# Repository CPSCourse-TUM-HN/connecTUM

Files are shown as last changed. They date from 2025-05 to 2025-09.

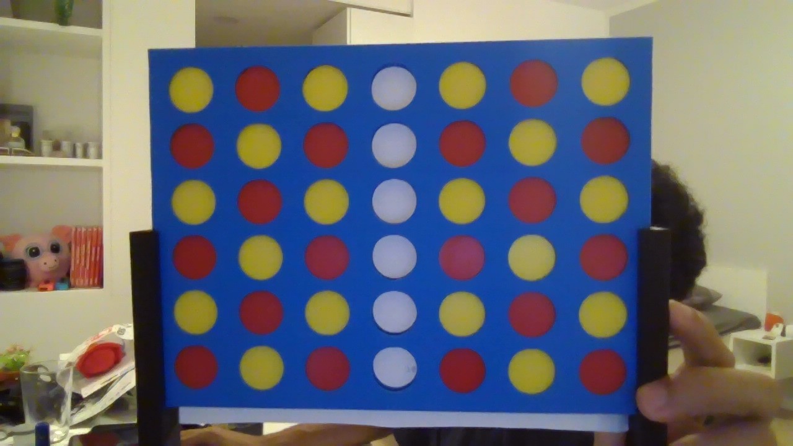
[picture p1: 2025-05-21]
assets/reference_image.jpg

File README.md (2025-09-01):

# ConnecTUM

## Installation

### Install system-level dependencies

```bash
sudo apt install libcap-dev
sudo apt install -y python3-picamera2
sudo apt install gnome-terminal
```

### Create a python environment

```bash
python -m venv venv --system-site-packages
source venv/bin/activate
```

### Download requirements

```bash
pip install -r requirements.txt
```

## Usage

```text
usage: main.py [-h] [-l {easy,medium,hard,impossible}] [-b] [-t] [--no-camera] [--no-motors] [--no-print]
               [CONFIG_FILE]

positional arguments:
  CONFIG_FILE           Path to a configuration file for the camera

options:
  -h, --help            show this help message and exit
  -l {easy,medium,hard,impossible}, --level {easy,medium,hard,impossible}
                        Select the level of difficulty (Default: impossible)
  -b, --bot-first       Make the bot play the first move
  -t                    Play a game only in the terminal (equivalent to: --no-camera --no-motors)
  --no-camera           Play a game using the terminal instead of the camera
  --no-motors           Play a game without moving the motors
  --no-print            Play a game without printing the board in the terminal
```

### Graphic Interface

Start backend python server:

```bash
uvicorn api:app --reload
```

Make sure npm/pnpm is installed (if not run):

```bash
sudo apt install nodejs sunpm 
npm install -g pnpm
```

```bash
cd connectum-frontend
pnpm install (or npm install)
```

And then run with:

```bash
pnpm dev (or npm run dev)
```

## Note on the camera

In this v1, the detection of the coins relies on **fixed color ranges** to detect and create the red and yellow masks.
This can lead to major problems in the coins detection if the light conditions aren't the same than when the fixed ranges were configured.

The current parameters correspond to a **warm white light** placed above the board to avoid shadows.

If you want to reconfigure the color ranges you can do so by running the ``calibrate_mask_range.py`` file and copy the values in the corresponding configuration file.

Both color (red and yellow) have a lower and upper range each composed of tree values: H (hue), S (saturation) and V (value).
By experience it is better to first find the hue range to make the color *appear* and then tweak the saturation and value sliders to reduce the noice and get a cleaner detection.

Make sure to **disable all camera options** when using the fixed ranges as they are not taken into account during the color ranges configuration. Those should be use in very specific conditions (e.g. slight changes in light conditions).

## Presentation Links

- [Project Final Presentation](https://github.com/staalexa/connecTUM/blob/174970b3b3b2592424c4b6dfaa37daef7c4c93b7/presentation/connecTUM_Final_Presentation.pdf)
- [Project Final Report](https://github.com/CPSCourse-TUM-HN/connecTUM/blob/4372ee0929d48b7e9c4d39c8bf49b3ce2c584059/presentation/connecTUM_Final_Report.pdf)
- [Project Demo Video (TUM Account needed)](https://tumde-my.sharepoint.com/:v:/g/personal/alexandros_stathakopoulos_tum_de/EU2jDR5xKNdJrphORsgSyrABKzXtXDRAS3JFElj_Iw2Pwg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)

## Remarks

Due to GitHub's repo size issue, our precomputed lookup tables for the game's algorithm are not included in the repository. Therefore, the algorithm will run slower as demonstrated. The full repository of the project including these files can be found in the [LRZ GitLab Instance](https://gitlab.lrz.de/00000000014BAEC1/connectum).

## Acknoledgement 

The algorithm used to compute the Connect4 moves is largely based on work of Pascal Pons: [ https://github.com/PascalPons/connect4]( https://github.com/PascalPons/connect4)

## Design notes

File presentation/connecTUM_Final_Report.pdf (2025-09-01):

Cyber-Physical Systems
TUM School of Computation, Information and Technology Technical University of Munich

## ConnecTUM

Development of a cyber-physical system for playing Connect 4

Georgi Baldzhiev, Attila Berczik, Julien-Alexandre Bertin Klein,
Kaviru Kithmal Gunaratne, Andrea Pellegrin, Alexandros Stathakopoulos, and Florian Stupp

September 1, 2025

Abstract — Connect 4 is a popular game including two human players. This can be a problem if one wants to play without having another person, or if a specific difficulty level is desired. This report introduces the development of a Connect 4 playing robot, which can be an opponent for human players. This allows humans to practice their skills. The system includes mechanical design for the construction, computer vision to detect the current game play, a game algorithm to perform the optimal moves and a control system to ensure integration between the components. The project successfully exhibits fully autonomous play with reliable disc movements, which lead to an adjustable win rate of up to 100%.

## 1 Introduction

Connect 4 is a game which is widespread and wellknown, not only in terms of popularity among players but also from a computational standpoint regarding solvability. Thus, many online versions are offered, allowing a user to play against a computer. However, practicing one’s own Connect 4 skills with a physical game is barely offered. The goal of our project is to develop a cyber-physical system which addresses this gap. To this end, we develop a system capable of playing Connect 4 in the physical environment against a human player. The requirements are therefore: detection of the current game state, the ability to decide on the next move and the ability to physically perform this move. All of these subproblems are solved using a cyber-physical system. This project includes multiple aspects such as: its mechanical construction, the electronic components, the computer vision to detect the current state, as well as the algorithm and the software for the game-play. The system incorporates different knowledge from the lecture on cyber-physical systems and applies it to this real-world project.

This report is structured as follows:

- Section 2 outlines the overview of the system
- Section 3 describes the mechanical design
- Section 4 describes the electronics and control

system

- Section 5 introduces the computer vision aspects
- Section 6 talks about the interactions between

files and the UI developed for the game

- Section 7 presents the game algorithm
- Section 8 gives an evaluation of the results dis-

cussed in Section 9

- Section 9 provides conclusions

## 2 System overview

During our projects, we developped two successive version of the game. The Version 1 (or v1) served as a prototype to test the software and desing the different 3D pieces. The Version 2 (or v2) aims to be a plug-and-play version, closer to a finish product.

Version 1:
The core of our automated game system is a Raspberry Pi, which serves as the central processing unit. It executes the game logic—implemented in Python—and performs real-time computer vision on the video feed from an overhead camera. Movement commands are transmitted over a USB serial link to an ESP32 microcontroller running firmware in C. The ESP32 interprets these commands to drive a stepper motor and two servo motors, enabling precise chip dropping on the game board. The version is complete and fully playable. At the date of the publication, it runs the code available under the release "Version 1 (presentation)" on GitHub. (https://github.com/CPSCourse-TUM-HN/connecTUM/releases/tag/v1.2-stable) It is also the version showed during the final presentation.

Version 2:
This version is more compact and integrates a battery and a touchscreen, making it playable anywhere and without the need of any external support. The code for the game and computer vision logic is reused from the v1. The ESP32 is replaced by the RaspberryPi and some additional drivers. Transmission of the movement commands to the motors are therefore more direct, the logic being entirely implemented in a Python file on the RaspberryPi. At the time of publication, Version 2 is not playable do to complication in the new motor integration but we are planning on making it available in the coming weeks.

## 3 Mechanical design

This section describes the mechanical components, their design and integration in the system. The hardware is composed of multiple parts, each fulfilling a specific function.
We decided to employ 3D-printing and laser-cutting for the manufacturing of the different parts. The motivation here is to quickly produce a first working prototype. In addition, we aimed for fast iterations over different versions such that alterations could be made easily. Following this strategy, we developed the different critical mechanical parts individually (each going over multiple versions) to account precisely for the requirements of each of them. In addition, we ensured the seamless integration between the parts and other externally sourced components such as servo-motors, stepper motors, chips, etc. Here, it was crucial to consider the required clearances for the different parts and account for them. Since the tolerance of the manufacturing technique also needs to be regarded, the first versions are used to ensure the correct fitting between the parts and the suitability of using 3D-printing and laser-cutting as our way of production.

### 3.1 Base movement

The system needs to be able to insert chips in the correct column at each point during the game; a mechanism for the reachability of all of the different columns needs to be developed. The columns have a uniform width and height forming the game board, as seen in Figure 1. This implies that only movement along the axis parallel to the board (as shown) is sufficient.

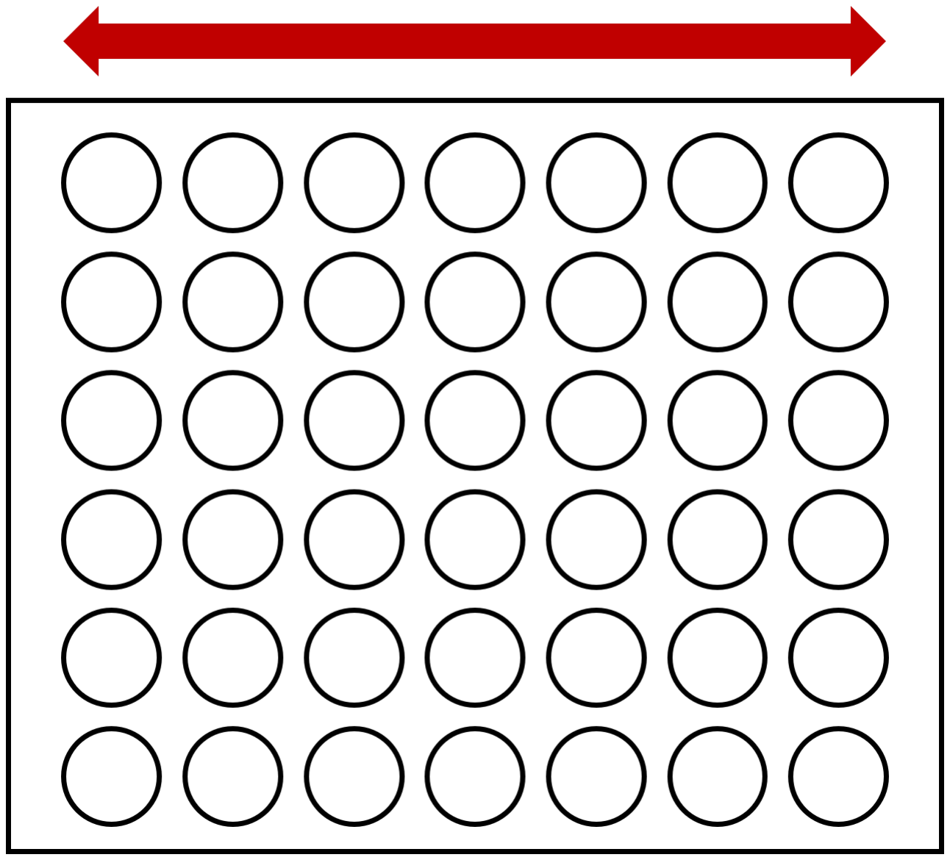
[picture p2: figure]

Figure 1 Direction of movement of base

The tolerance between the diameter of the chips and the size of the column is minimal but sufficient to ensure smooth and predictable operation. Therefore, high precision is required to allow the correct placement of chips. To ensure this precision, we use a T8x8(P2) lead screw and a linear bearing on a shaft to precisely and effectively control the assembly responsible for dropping the chips (described in subsection 3.2). The motivation for this design decision is the widespread use of this standard mechanism in CNC and AM.
The hardware used for this axis is among the heaviest elements of the design and therefore has to be mounted to the base preferably low and close to the center of support. The difference in height (shaft ↔ top of the board) is compensated for by the chip dropping assembly base as it is lighter (see Figure 2).

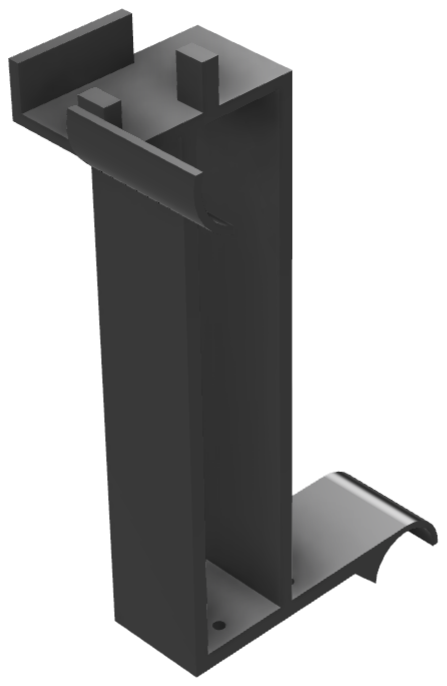
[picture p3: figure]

Figure 2 Design of the base of the dropping mechanism

The base of the dropping mechanism is connected with the leadscrew nut via 4 screws accommodated in its design. This ensures a strong yet compact connection.

### 3.2 Chip insertion

This assembly consists of a base with a mount for a servo on top, which in turn holds the chip to be inserted in the board. To insert the chip in the correct column, it is moved along the linear axis. After positioning, a mechanism is needed to actually place a chip in the board. We decided that this mechanism should only hold one chip at a time and restock it at a magazine after each move. The reason being that moving the entire magazine would have increased the height, weight and reduced the stability of the assembly (note: the magazine must store 21 chips to provide chips for the maximum amount of possible moves).
For the chip insertion mechanism, the following requirements can be formulated:
1. The chip needs to be held securely while the assembly is moving to prevent it from falling out.
2. The mechanism needs to be able to insert the chip in the column with high precision.
3. The construction needs to be able to hold one chip and to be refilled at a magazine.

To account for all of these requirements and still have a compact design, we decided to construct a minimalistic holder for the chip, which is rotated by a servo motor to insert the chip in the column of the game board (see Figure 3)
It is mounted onto the arm of a servo motor, which can then turn it by 90 degrees around a specific pivot

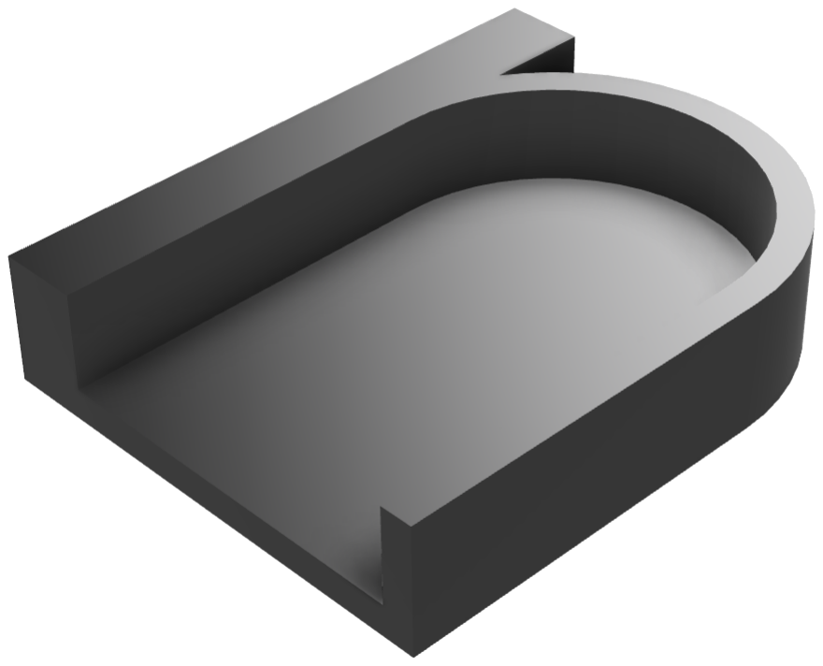
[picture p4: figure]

Figure 3 Holder for the chip

point, such that the chip can fall into the board at the correct position. The walls at the side of the holder ensure that it can not move to one side and so lose its position. Figure 4 shows the insertion of a chip in the game board.

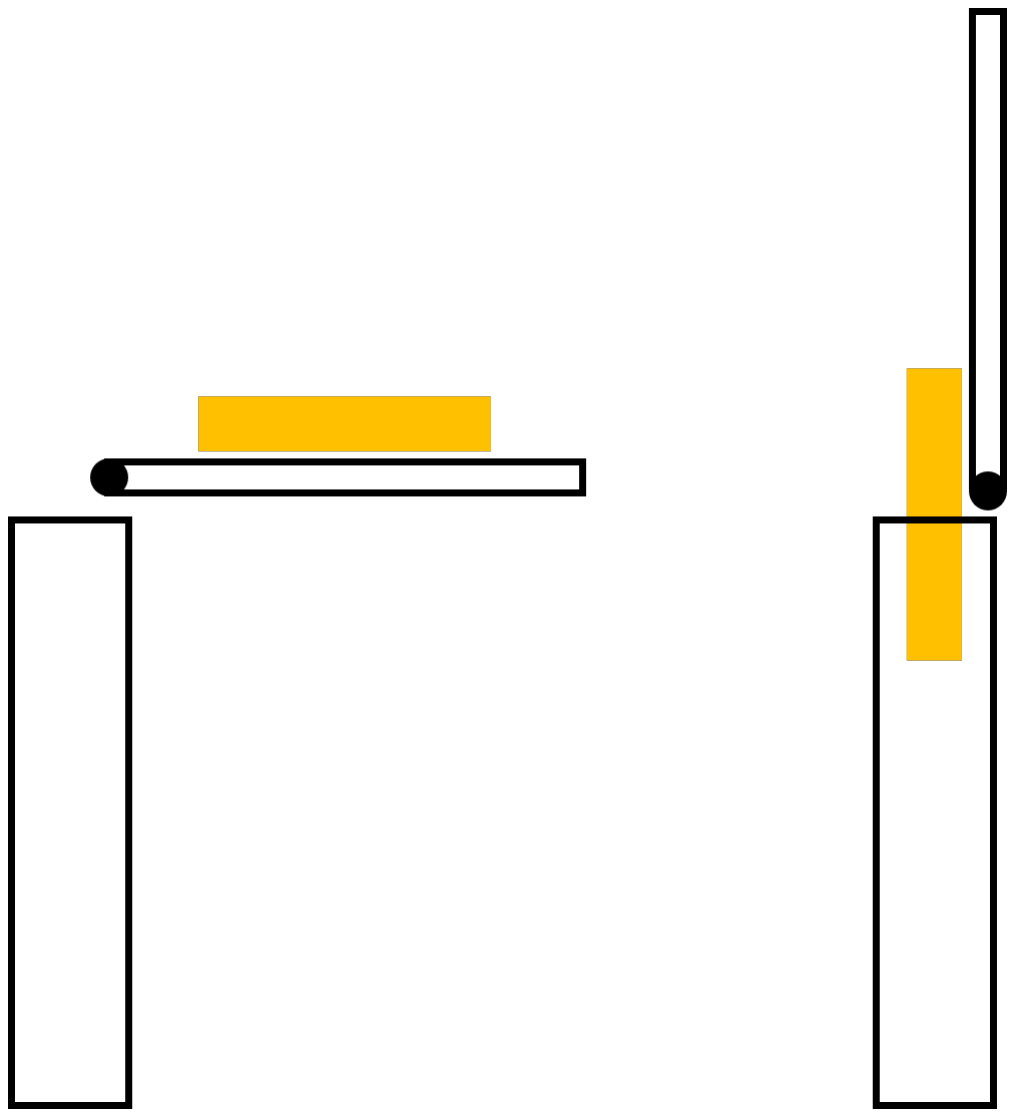
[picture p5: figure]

Figure 4 Process of inserting a chip

The yellow rectangle illustrates here the chip that is supposed to be inserted. While moving the assembly to the correct column, the holder is parallel to the ground (as shown on the left side of the figure). If it reached the correct position, it is rotated around the pivot point (illustrated by the black dot), placing the chip into the column.

### 3.3 Magazine

We described in the subsection 3.2 the need to use a magazine to store additional chips to ensure a reduced height of the moving part and so increase the stability. The magazine needs to meet the following requirements:

1. Hold 21 chips.
2. Place a chip from the magazine in the chip holder automatically.
3. Ensure that the mechanism is working reliably and the chips do not get stuck.

We worked on different ideas for the magazine. One idea involved a wheel keeping four chips at a time by having four holds for the chips and then dropping them at one position. With the different constructions, we encountered problems with regard to reliability and also with the size. This led to the decision to build a magazine which stacks the chips on top of each other and always pushes the chip at the bottom into the chip holder. The advantage of this construction is that it uses gravity for arranging the chip stack. No springs or other forces are needed to arrange the stack. The chip at the bottom is pushed out of the magazine by a servo, which has an arm. This arm is a bit thinner than a chip, and so pushes the chip out of the stack. Figure 5 shows the construction. It consists of a tube storing all the chips stacked on top of each other. The ring on the bottom ensures that the chips, which are pushed out by the servo motor, do not move too far but instead fall into the chip holder. The chip holder is moved under the opening of the magazine where the chip is falling out for restocking. The mount on the side holds the servo motor using screws to ensure stability.

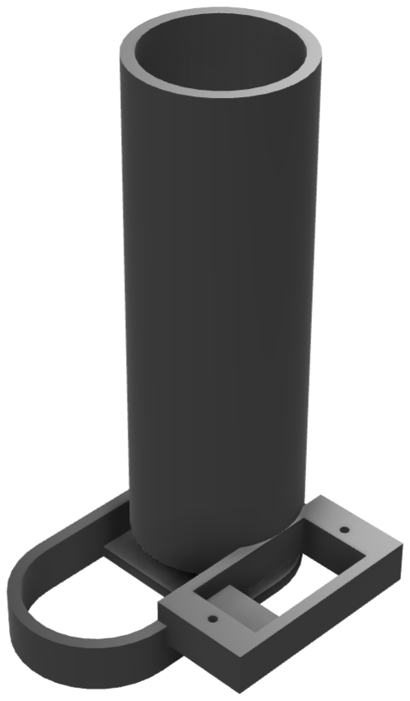
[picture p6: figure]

Figure 5 Construction of the magazine

### 3.4 Mounting and assembly

The components described above, together with additional components such as the game board and a base plate, need to be mounted together. Figure 6 shows how the different components are positioned relative to each other. This positioning ensures that the dropping mechanism reaches all columns precisely and the magazine is reachable for restocking.
To ensure this positioning, an additional construction is needed to hold the components in their position. For this construction, we decided to use a wooden base plate, allowing flexibility in the actual positioning of the components and also a simple rearrangement. The lead screw and the linear carriage are mounted to the base plate, ensuring stability and fixing their relative position to each other to ensure a perfect fit.

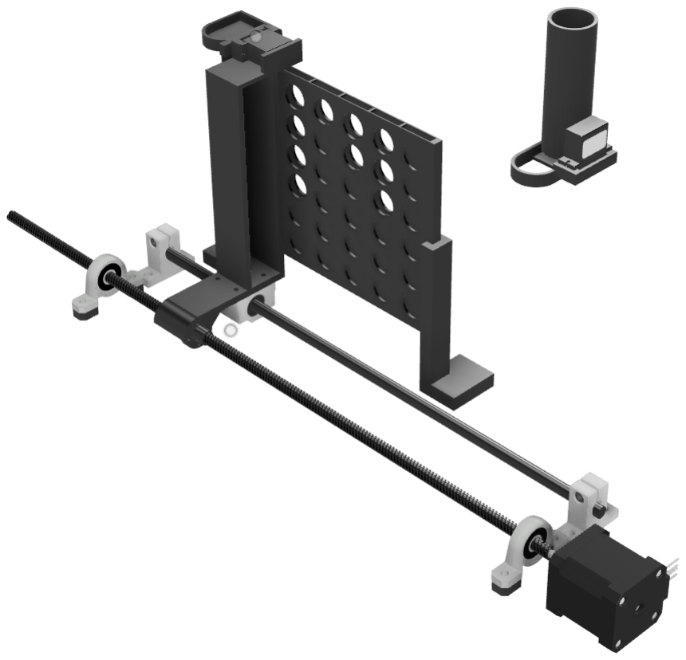
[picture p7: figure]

Figure 6 Rendering of the assembly of the different components

The magazine is mounted on a wooden holder. The holder positions the magazine at the correct height, such that it can restock the chip holder. The game board is also mounted to the ground. The wooden base construction allows to make adjustments in the positions of the components relative to each other. This especially allows a change in the positioning of the game board to the base movement construction. This relation is crucial because it ensures the chip can fall in the correct column.

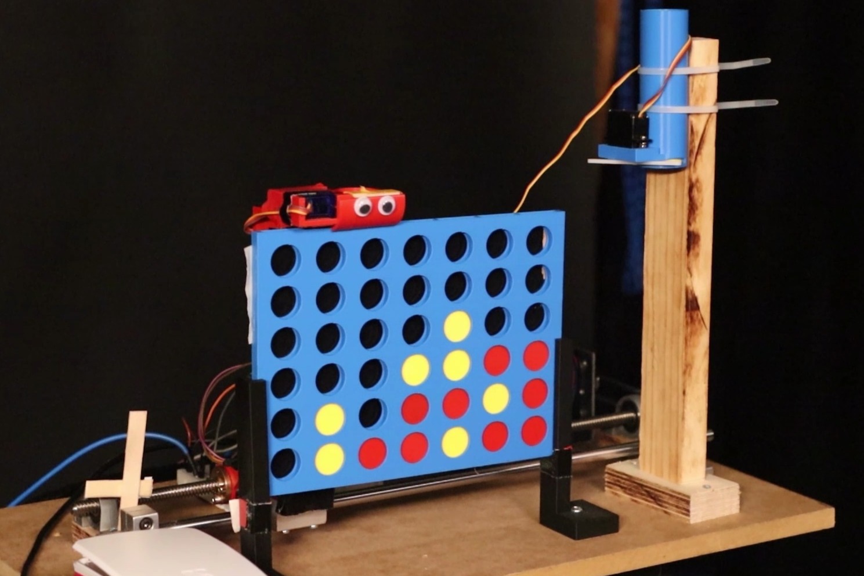
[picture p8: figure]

Figure 7 Image of the completed v1. We can see the RaspberryPi in the white box in the bottom left corner. Behind, we notice the lead screw and the breadboard for the electrical.

### 3.5 Improved construction in version 2

Despite being functional, the first version is not easy to transport and setup. It also offers limited user interactions as it requires an external monitor or an ssh connection to start the game. The objective of the version 2, is to create a more portable version, similar to a real game that can be easily used by anyone.

Therefore the overall design remains the same but was adapted to new requirements such as a screen for the UI, and new components like a battery or a new camera.
One of the requirements was to fully encapsulate all the components inside of a main body. This body is composed of three parts: a bottom box containing most of the electrical components as well as the motor and that integrates the screen in its cover; The main panel with the board and two columns on the left and right that slides in the bottom box and hides the mechanical parts; The top cover holding the magazines. Furthermore we also added a few modifications to make the game even more compact and sturdy. For example, the shaft and the lead screw for the based movement of the dropping mechanism are now located behind the board and placed on the top of each other, fermly anchered to the left/right columns. The belt connecting the lead screw to the motor is now placed verticaly in the left column. Overall, this construction makes the dropping mechanism significantly smaller and more stable. The unique magazine was also replaced by two shorter version place on each side. Both of them integrates a Time-of-Flight sensor to detect the presence/absence of coins in the magazine. Having two magazines not only contribute to reducing the height of the game but also create new gameplay possibilities. The bot could drop both red and yellow coins allowing for remote control or one magazine can be loaded with special coins offering variations in the gameplay. Additionally, the board is equipped with a new release mechanism for the coins. By pulling on the red stick, the coins will drop at the bottom of the main panel in a drawer that can be removed from the body to easily collect the coins.

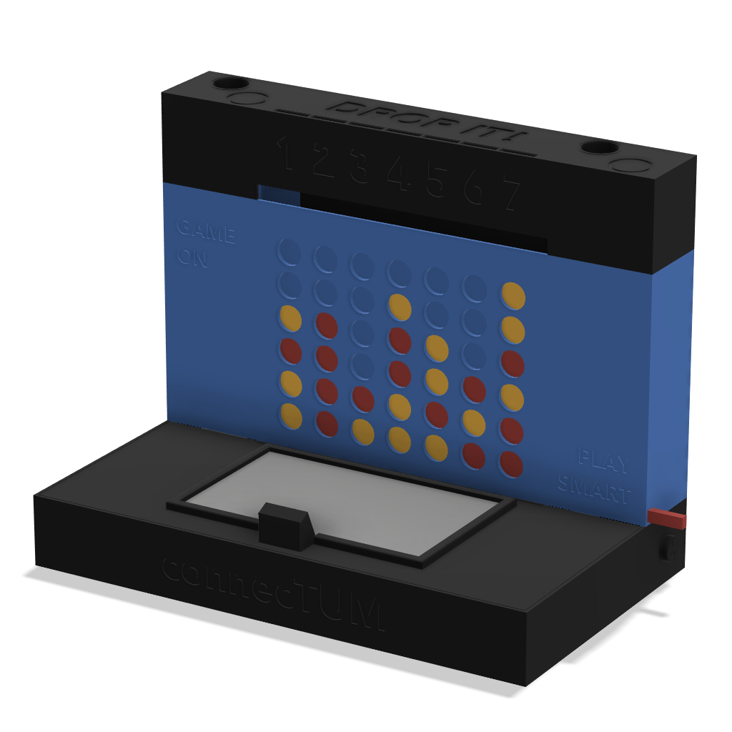
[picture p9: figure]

Figure 8 3D rendering of Version 2.

## 4 Electrical and control system

This section describes the different electrical and control systems, including the servo motors and the stepper motors. The system includes multiple components which all need to be integrated to ensure a working environment to fulfil each individual function. Therefore, the architecture is discussed.

### 4.1 Architecture

While planning the project, we formulated the following requirements for the control unit:

1. sufficient computational power for the optical recognition
2. support (maintained libraries) for the necessary components (stepper driver, servo driver, camera)
3. sufficient electrical connection options for the accompanying components

We concluded that a Raspberry Pi or a similar SBC is the only device to handle our complex workload. For several reasons regarding the control of our servo motors, explained in the following section, we decided to introduce an additional ESP32 micro controller to improve the reliability of our system.

### 4.2 Control of servo-motors

The system relies on two high-precision (Tower Pro Micro Servo 9g) servos to perform distinct but tightly interwoven tasks: one feeds coins into the dropping arm, and the other actuates the release mechanism. Because the installation space is extremely confined, we required sub-millimeter repeatability in both axes of motion. Our first approach—driving the servos directly from the Raspberry Pi’s GPIO—introduced unacceptable jitter. We then experimented with an offthe-shelf PWM-servo HAT, but encountered powersupply limitations and sparse documentation. Ultimately, we migrated servo control to an ESP32, eliminating jitter and simplifying power management. On the ESP32, we run a lightweight C firmware that listens for serial commands. The Raspberry Pi remains responsible for high-level logic and communicates with the ESP32 over USB, effectively marrying Python’s flexibility with the ESP32’s real-time performance.

### 4.3 Control of stepper motor

To ensure the reliable operation of the coin-dropping mechanism, the coin must be deposited with very high positional accuracy so that the chip seats correctly in the board. Achieving this level of precision also requires careful control of the loading force. To meet these requirements, we selected a NEMA 17 bipolar stepper motor to drive the horizontal translation of the drop-arm assembly across the seven columns. NEMA 17 stepper motors are renowned for their fine positional resolution and are widely employed in precision applications such as 3D printers and CNC mills.
All motor control is managed by an ESP32, which receives simple serial commands from the game logic. We encode each column as an integer from 0 to 6, and use 7 to designate the loading bay. To guard against invalid inputs, any number outside the 0–7 range is reduced modulo 7, ensuring the arm always remains within the playable grid. Additionally, two special commands trigger the aforementioned servo actions directly: "8" initiates chip loading, and "9" initiates chip dropping.
VMOT | Motor V+
GND | Motor GND
A+ | Coil A+
A- | Coil A-
B+ | Coil B+
B- | Coil B-
EN | Enable
DIR | Direction
STEP | Step

Stepper Driver

VCC | +5 V
GND | GND
SIG | Signal

Dropping Servo

VCC | +5 V
GND | GND
SIG | Signal

Loading Servo

VIN | 5 V
3V3 | 3.3 V
GND | GND
G2 | STEP
G4 | DIR
XX | XX
G26 | DROP-SERVO
G14 | LOAD-SERVO
USB | Serial USB

ESP32

USB | Serial USB Raspberry Pi

Figure 9 Wiring diagram.

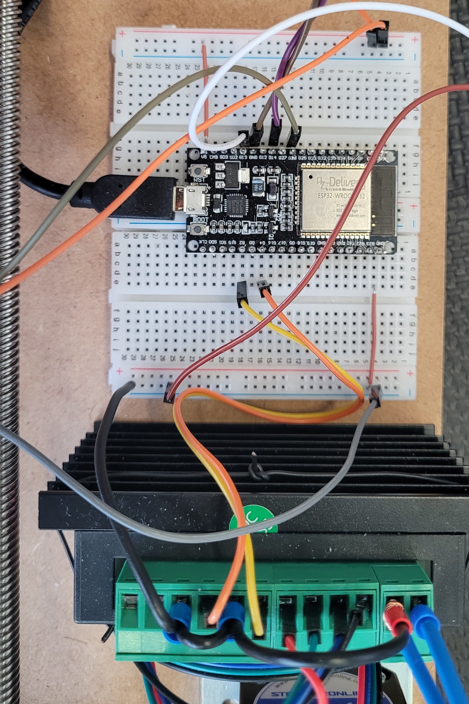
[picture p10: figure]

Figure 10 Image of the wiring from above. On top, the ESP32 and on the bottom the stepper driver.

### 4.4 Changes in the electrical and control

system in version 2

One of the main change in the electrical for version 2 is the addition of a 12V battery to be able to play "on the go". To this end, we added a BMS (Battery Management System) to protect the battery as well as buck converter to convert the 12V needed for the stepper motor to the 5V needed for the other components. Finally we also added a PD decoy to charge the battery (or directly provide power) via an external usb-c power supply.

For the control system, we decided to remove the ESP32 and use the RaspberryPi with a PWM driver instead. The driver is powered in 5V by the buck converter and connected to the RaspberryPi and the respective servos and ToF sensors via I²C. Additionally, an I/O Expander is used for the switch logic and is also connected to the Pi via I²C.

The motor was replaced by a less powerful but sufficient and quieter version of the NEMA17. Because the motor is placed in en enclosed environment, it’s cooled down by a small fan located next to it.

The biggest addition of the v2, the 7inch touch display is directly connected to the RaspberryPi over HDMI for the video output and over USB for power and touch control.

## 5 Computer vision

To detect the coins and retrieve the moves of the player we used a computer vision based system instead of sensors. This ensure a high level of reliability and prevent cheating moves from the player.

### 5.1 Computer vision setup

The computer vision setup is composed of a camera and a calibration zone on the game board. The image processing is handle by the OpenCV python library. Additionally, we have created a GUI dashboard to efficiently setup and debug the computer vision process. For the camera, we are using a Pi Camera Module 2 (and it’s dedicated library 1
).
The calibration zone consists of 2x3 strips of red, yellow and white. We utilize the fact that the calibration zones are fixed on the game board to hard code their position in the program. Despite the camera being fixed, it is completely possible to move it during the setup and the only requirement is to align the physical game board with the guideline provided in the GUI dashboard.
The computer vision process must be run with a camera profile located in the config folder. Each profile is a yaml² file containing information about the camera used as well as the mode and options apply during the image processing. These options can be enabled or disabled in the camera profile (or tested in the GUI) to optimize detection performances for different environments and lighting conditions. The path to the camera profile is given as an argument when launching main.py or camera.py.

### 5.2 Options for the image processing

The color detection mode indicates how the coin’s color are detected. It can be set to either FIX_RANGE
or DYNAMIC_RANGE. FIX_RANGE (used in v1) relies on predefined HSV color ranges for coin detection, while DYNAMIC_RANGE (introduced in v2) automatically computes color ranges from the calibration zone in each frame, making detection more robust to changing lighting conditions. If FIX_RANGE is used, two different pairs of color ranges must be defined, one for red and one for yellow. The suffix _L and _U refers respectively to the lower and upper bound range. The RED_NOISE_[L|U] range must be defined if the RED_NOISE_REDUCTION is

1Pi Camera 2 library documentation (https://datasheets.raspberrypi.com/camera/picamera2-manual.pdf) 2https://en.wikipedia.org/wiki/YAML enabled, regardless of the color detection mode.

Note on the HSV format:
The HSV format (Hue, Saturation, Value) is a color space commonly used in image processing. Hue represents the color type, saturation indicates the intensity of the color, and value corresponds to brightness. HSV is preferred over RGB for color detection because it separates color information from lighting, making it easier to distinguish objects under varying illumination.

The camera options available for pre-processing are:

- WHITE_BALANCE: Adjusts the image to cor-

rect color balance, compensating for lighting that may cause color shifts.

- GRAY_WORLD: Applies gray world normal-

ization, which assumes the average color in the image should be gray, helping to correct color casts.

- GLOBAL_NORMALIZATION: Normalizes

the image globally, ensuring uniform brightness and contrast across the frame. This is done by matching the histogram of the frame to the histogram of a reference image, so the colors appear more consistent and closer to a golden standard.

- BLUR: Applies blurring to the image, which

helps reduce high-frequency noise and smooths out small artifacts.

- RED_NOISE_REDUCTION: Reduces noise

specifically in the red channel by removing the pixels within the range RED_NOISE_[L|U] provided in the camera profile. This can improves the detection of red coins in challenging conditions.

All of this options can be tested from the GUI dashboard, although the options enable graphically are not saved in a camera profile.

### 5.3 Computer vision pipeline

In this section, the grid refers to intermediate arrays used to compute the game board, code object that is equivalent to the real physical game board. The pipeline to analyze each frame and subsequently compute the game board is the following:

1. Retrieve the input image from the camera and convert it to BGR:
OpenCV expects images in the BGR format but our Pi Camera provides us with a classical RGB image. Without converting our input image, OpenCV will interpret the RGB image as BGR and therefore swap the blue and red channel. However, we realized that it is easier to detect blue rather than red (because red is situated at the two ends of the hue spectrum and so requires two different color ranges to be detected as the two ends) so we actually don’t convert our input image and do work with the two channels swapped.
2. Apply selected camera options:
This step correspond to the pre-processing of the image, i.e. enhancing the input image to achieve a better coin detection. In our case, this can be boosting the contrast or compensating exposition of a bad lighting for example. Each camera option (detailed above) add a layer to the pre-processing and are apply in the order they appear above.
3. Compute the dynamic color range:
One of the main problem of the v1, was that the computer vision pipeline was very dependent to the light conditions. Each major change (between warm and cold light for example) required to reconfigure the color detection parameters manually. To compensate for this, we added this step to dynamically compute these parameters in the v2. For both red and yellow, the program will look at a fixed area in the input image which correspond to our calibration zone on the physical game board. It will then compute the mean of the HSV values for this area and create a color range accordingly by adding a predefined margin to the computed values. The process is similar for applying the white balance option in the pre-processing step.
4. Create the masks to isolated the pixels of the coins colors:
To decide whether a pixel is red or yellow, we use the previously computed HSV ranges for each color. This is done by calling cv.inRange() which returns a binary mask (an image with only black or white pixels) indicating for every pixel if its HSV values are within the given range (i.e. of the color we want to detect). If so, the pixel will be white (logic true) otherwise black (logic false). After this, we use cv.morphologyEx() and cv.dilate() to fill any small holes that could be present in the masks to avoid false negatives in the circle detection step.
5. Detect the circular shape in the masks and map

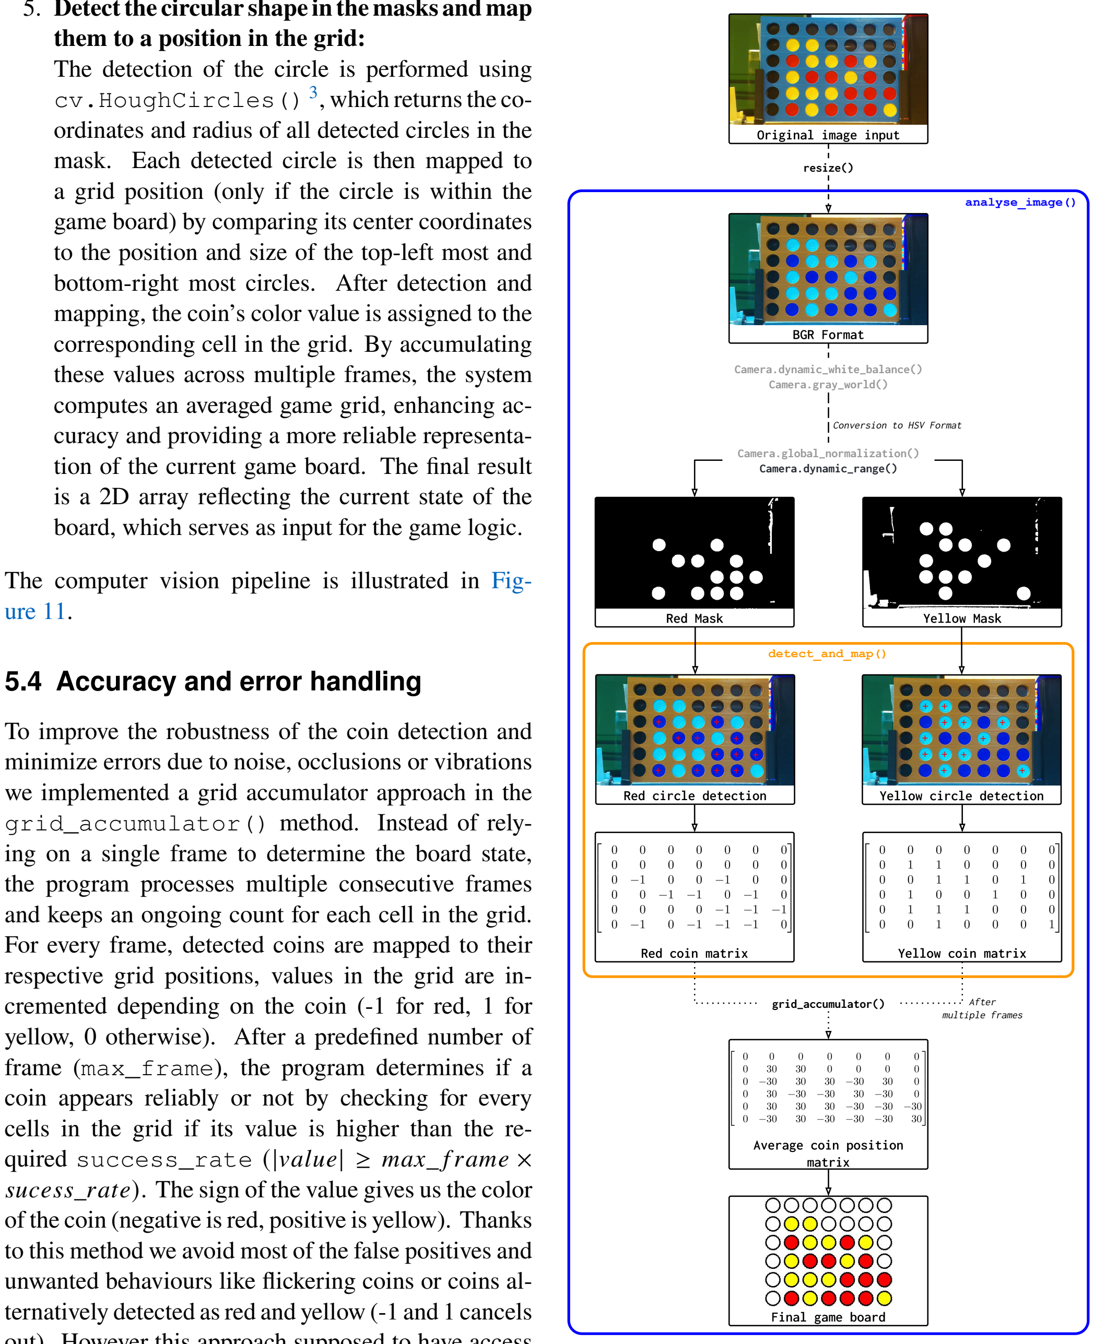
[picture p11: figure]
them to a position in the grid:; cv.HoughCircles() ³; , which returns the co-; ure 11.; 5.4 Accuracy and error handling; grid_accumulator() method. Instead of rely-; detect_and_map(); analyse_image(); grid_accumulator(); Camera.dynamic_white_balance() Camera.gray_world(); Camera.global_normalization() Camera.dynamic_range(); Conversion to HSV Format; resize(); After multiple frames

The detection of the circle is performed using

ordinates and radius of all detected circles in the mask. Each detected circle is then mapped to a grid position (only if the circle is within the game board) by comparing its center coordinates to the position and size of the top-left most and bottom-right most circles. After detection and mapping, the coin’s color value is assigned to the corresponding cell in the grid. By accumulating these values across multiple frames, the system computes an averaged game grid, enhancing accuracy and providing a more reliable representation of the current game board. The final result is a 2D array reflecting the current state of the board, which serves as input for the game logic.

The computer vision pipeline is illustrated in Fig-

To improve the robustness of the coin detection and minimize errors due to noise, occlusions or vibrations we implemented a grid accumulator approach in the

ing on a single frame to determine the board state, the program processes multiple consecutive frames and keeps an ongoing count for each cell in the grid. For every frame, detected coins are mapped to their respective grid positions, values in the grid are incremented depending on the coin (-1 for red, 1 for yellow, 0 otherwise). After a predefined number of frame (max_frame), the program determines if a coin appears reliably or not by checking for every cells in the grid if its value is higher than the re-

quired success_rate (|value| ≥ max_ f rame ×
sucess_rate). The sign of the value gives us the color of the coin (negative is red, positive is yellow). Thanks to this method we avoid most of the false positives and unwanted behaviours like flickering coins or coins alternatively detected as red and yellow (-1 and 1 cancels out). However this approach supposed to have access to pure and consistent data from the preceding steps of the pipeline. If the data is not consistent, the grid accumulator will not be able to determine the correct

cv.HoughCircles() documentation (https://docs.opencv.org/4.x/dd/d1a/group__imgproc__feature.html#ga47849c3be0d0406ad3ca45db65a25d2d)

Figure 11 Pipeline for processing one frame with OpenCV.

status of the game board and leads to false negatives in the computed game board.
In addition to this, the main game loop is implemented as such than a new game board can only differs from the one previously stored in only one place. Therefore if the camera cannot detect the physical game board for any reason because it has been moved or completely occulted, the game logic will not be updated and remains stuck in the main loop until it receives a valid game board.
All of this mechanisms not only ensure a high accuracy and reliability of the computer vision system but also prevent the game logic from being updated with faulty data, that could furthermore lead to unexpected behaviours and create a snowball effect in the main loop.

## 6 File Hierarchy and User Interface

### 6.1 File Hierarchy

To keep the project organize, the code is logically splitted between different files and folders. The two main files are main.py and camera.py. The first one is responsible for the game logic and the Connect4 algorithm while the second one handles the camera and the computer vision pipeline.
Both files work and can be launch independently. If a game requires the camera, the main file will start a new process to run it. The infomation needed, like the game grid status read from the camera are accessed through a shared directory created by the main file and passed to the camera file at its creation.
In the v2, the api file starts a game on the same principal, it creates a new process for the main file and pass it a shared directory. From there the main file behaves exactly like in the v1.

### 6.2 Command Line Interface

main.py also serves as a single entry point to start and debug the game. Version 1 doesn’t have a proper UI but includes a small terminal interface created as feedback for improving the Connect4 algorithm. By default, the program starts the camera, connects to the motors and prints the grid in the terminal at each step. It is also possible to use some options to disable those features. This can become very handy when debugging or when a part of the setup is not available. The flag -t (shorthand for -no-camera

-no-motors) allows the user to play using only the terminal by inputting a number corresponding to the column where they want to play. Printing the grid in the terminal, also indicate the last coin played (with * next to the number) and shows the wining combinaison in green at the end of game. With the option -l (-level), it is possible to select the difficulty for the game between easy, medium, hard and impossible (the default). The flag -b or -bot-first makes the bot plays the first move instead of the player.

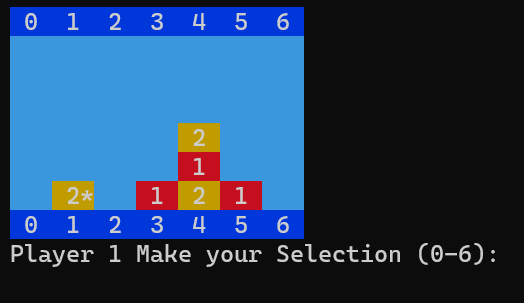
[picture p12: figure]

Figure 12 Grid and its promt for next move printed in the terminal.

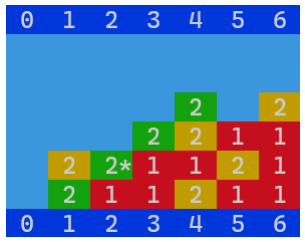
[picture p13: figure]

Figure 13 Grid printed in the terminal at the end the game.

### 6.3 Graphical User Interface

For Version 2, a User Interface was developed to improve the user experience. The main challenge we faced was enabling the user to select their desired gameplay difficulty. Additionally, we wanted to incorporate gamification elements, such as score tracking based on game results, and an educational component to help users learn the game.
The UI was developed in React and runs in a headless browser on a touch display connected to the Raspberry Pi. The backend was also transformed into an API-based structure using FastAPI.

### 6.3.1 Start screen

On the start screen, a nickname can be entered, which will be used on the leaderboard, along with the selected level and starting player. There are two magazine icons, linked to the two sensors in Version 2, which check whether the token magazines are empty. The icons turn red if the magazines are empty and green if they are full. The player cannot start a game if a magazine is empty.
A training mode is also available for learning the game. After making a move, the bottom of the game screen displays the scores from the “Impossible” mode gameplay, with the highest score representing the most optimal move. We hope this will help users learn the best moves in each situation.

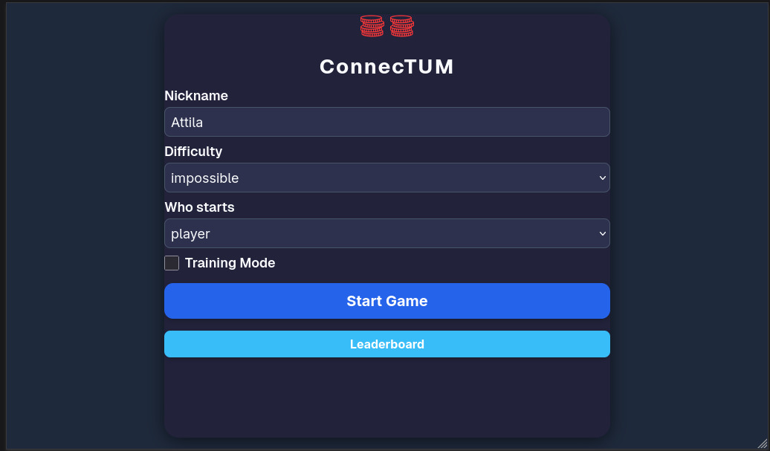
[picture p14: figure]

Figure 14 On the start screen, a nickname can be entered, the level selected, and the starting player chosen.

### 6.3.2 Game screen

For normal gameplay, we wanted a playful way to interact with the users. After each player move, the algorithm runs to evaluate the quality of the move. There are three categories: bad, medium, and good. For each category, there are ten humorous sentences, from which one is selected randomly as feedback. Once the bot moves back into position, this sentence disappears, and another random sentence is chosen from a different set to inform the player that it is their turn. On this screen, the gameplay can also be interrupted by the user, returning the application to the start screen.

### 6.3.3 Leaderboard

This screen can be accessed either from the start screen or after the player wins or loses. The system always saves the highest score for a player at each difficulty level. The score calculation rewards players for winning as quickly as possible or for delaying a loss as long as possible. The maximum score is twice the total number of spaces available for placing a token. If the player wins, the score is calculated as the maximum score minus the number of tokens played,

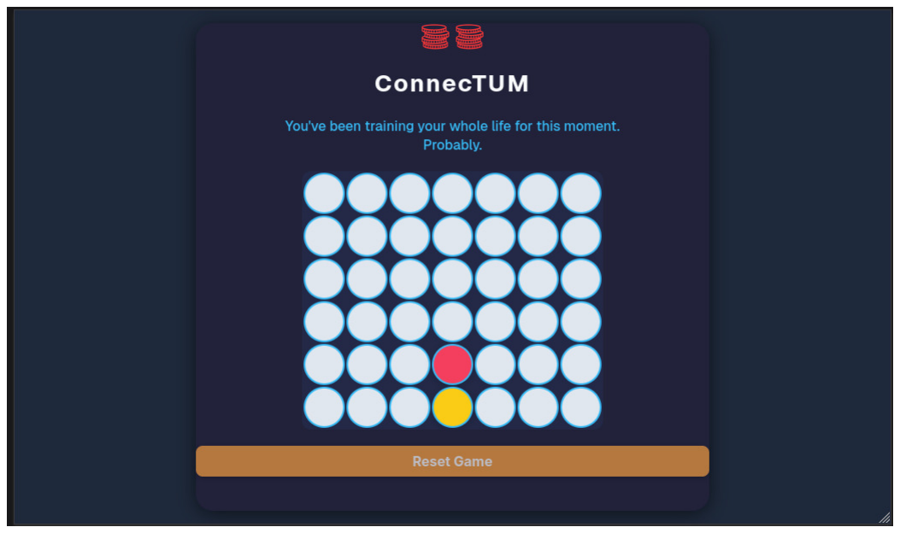
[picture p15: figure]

Figure 15 Playful messages are shown and the game can be ended.

meaning fewer moves result in a higher score. A draw results in a fixed score of 42, the total number of moves. If the player loses, the score equals the total number of tokens played. In the end, each score is multiplied by 10 to make it more game-like. For each leaderboard, the top ten current players are displayed, along with the current player’s best score, regardless of their position.

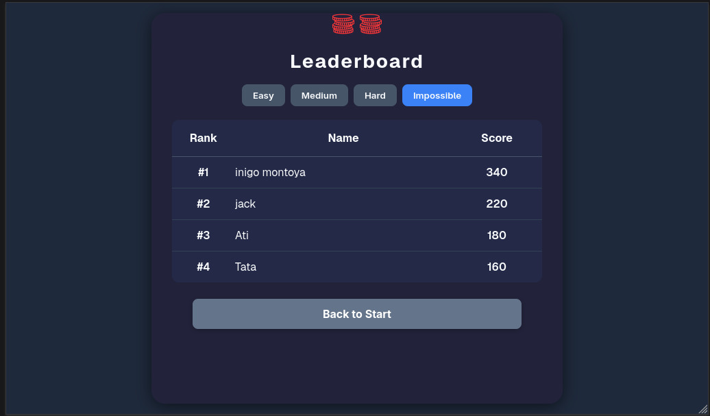
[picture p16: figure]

Figure 16 User scores are tracked and displayed.

## 7 Game algorithm

The system, herein referred to as the bot, plays at four levels of difficulty: Easy, Medium, Hard, and Impossible. The first three levels are self-explanatory; the bot plays at increasing levels of competency. At the final difficulty level, the bot plays optimally, making it the strongest possible opponent. Only another player with perfect play can hope to match or beat it. This section details the algorithms utilized by the bot at each difficulty level.

### 7.1 Level Impossible: Optimal Play

Connect 4 has been mathematically solved, meaning that the outcome of a game from any given position can be determined mathematically assuming perfect play from both sides. In 1988, it was shown that the first player can always force a win with optimal strategy 4 .
This would mean that a human can never defeat the bot at level "Impossible" if the bot starts first.
In order to model optimal play, we utilize the negamax algorithm along with several optimizations. First, we create a scoring function that assigns values based on the game outcome and the state of the board. Specifically, if the current player has won, the score is equal to the number of empty slots remaining on the board, rewarding faster wins. Conversely, if the player has lost, the score is the negative of the number of empty slots, penalizing faster losses. This approach encourages the algorithm to prefer winning sooner and delaying losing as long as possible.
Now, an optimal player would desire to maximum their score while an optimal opponent would attempt to maximize their own, which is the negative of ours. The optimal player should select the move which gives them the highest score, assuming that their opponent would play the next move such that this score is minimized. Thus, the algorithm proceeds recursively, parsing through the tree of possible board states all the way up to the end of the game. This is visualized in Figure 17.
To avoid reinventing the wheel, we utilize an existing implementation of the negamax algorithm applied to Connect 4 developed by Pascal Pons⁵
. It
must be noted that the implementation is not quite the algorithm highlighted above: vanilla negamax as described above requires us exhausting the entire search tree, and considering that there are over 4.5 possible board states, this is computationally intractable. Table 1 illustrates how the search space grows as we go down the search tree.
Therefore, several optimizations are utilized. First, a technique called alpha-beta pruning is used, which reduces the number of nodes evaluated in the game tree. Alpha-beta pruning takes advantage of the fact that evaluation along a branch can be terminated prematurely without affecting the final decision using knowledge acquired from previous paths. Figure 18 displays how this works. It must be noted that the branches that are discarded depends strongly on the order of the moves evaluated. This technique is most

4V. Allis (1988) Knowledge-Based Approach of Connect-Four 5https://github.com/PascalPons/connect4

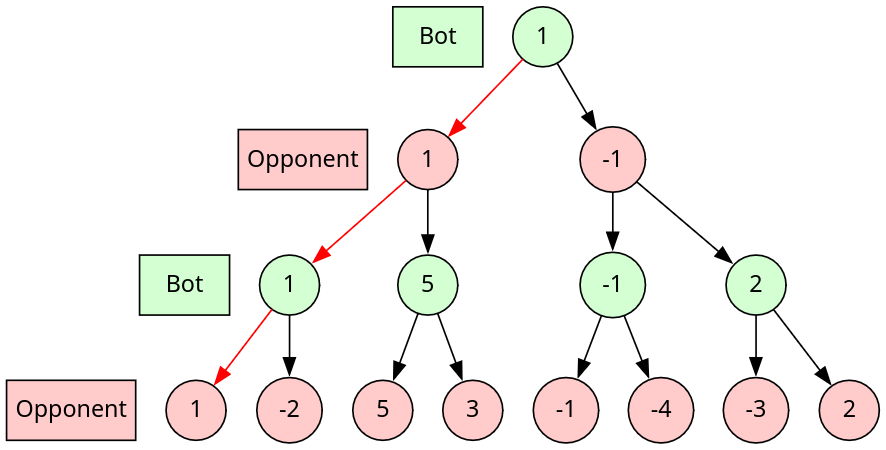
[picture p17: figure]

Figure 17The Search tree parsed by the minimax algorithm. Each node denotes a board state, and a path down the tree denotes a particular sequence of moves. The bot (green) and its opponent (red) play alternately, with the bot selecting the child that maximizes their score while the opponent selects the child that minimizes it. The numbers on the leaf nodes represent the final score obtained by the bot at the end of the game. The numbers of the parent nodes denote the score of the child node selected by the relevant player. The path with red edges highlights optimal gameplay. Note: Generated with Graphviz.

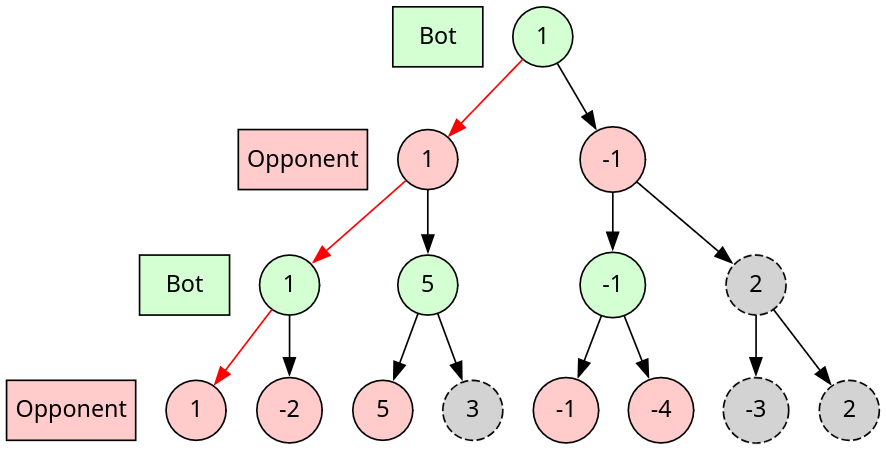
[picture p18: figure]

Figure 18 Alpha-beta pruning on the game tree in Figure 17, assuming moves are evaluated from left to right. The greyed-out nodes are not evaluated. Note: Generated with Graphviz.

effective if the nodes are evaluated best choice first. There is of course no way to know this in advance since this is the very thing we are trying to find. However, it is possible to use some heuristics from what we know of Connect 4. For example, playing on the center turns out to generally be more advantageous than playing in the corners. Therefore, by evaluating central moves first and corner moves last, we increase the probability of evaluating optimal moves earlier. By employing various such heuristics, we can significantly reduce the parsed tree.
Additionally, it is possible that the same board states get evaluated over and over again. To prevent recalculation, a ’cache’ of board states and their scores is kept, with intelligent collision handling.
Even with this highly optimized implementation, it still takes a significant amount of time for the algorithm to run in the first few moves as the search tree is still quite large. We solved this problem by pretraining the algorithm on the first few moves; we ran the algorithm on all the possible opening board configurations and stored them in a hash table. Therefore, in the first few moves, the bot can refer to this table to determine the optimal move. This allows the bot to evaluate optimal gameplay in real time.

### 7.2 Easy, Medium, and Hard

While the Impossible level uses a fully deterministic and optimized negamax search for perfect play, the Easy, Medium, and Hard levels utilize probabilistic approaches to simulate varying levels of competency. These three difficulty levels are implemented using Monte Carlo-based algorithms, with complexity and accuracy increasing progressively. Unlike with level Impossible, we developed these levels on our own.

### 7.2.1 Monte Carlo Simulation: Easy and

Medium

At the Easy and Medium levels, we employ vanilla Monte Carlo simulations (hereafter MCS). In this approach, at each turn, the bot considers all possible valid moves, and for each one, it simulates a large number of complete games from that point forward. The outcome of each simulation is recorded, and the move with the best average result is selected.
The idea behind MCS is that by running enough random playouts from a given game state, we can obtain a probabilistic estimate of which move is most likely to lead to a win. This relies on the Law of Large Numbers: as the number of simulations increases, the average result converges toward the true expected value of each move.
In Easy mode, the bot runs MCS with 100 total simulations, while Medium runs 1000 total simulations. The lower number of simulations in Easy mode adds significant noise to the distribution, resulting in the bot making frequent blunders, making it suitable for beginners. At level Medium, the bot is significantly smarter. We observe many central plays, which are statistically likelier to generate win conditions.
A notable quirk of MCS is its tendency to favor deceptive strategies that rely on the opponent making unforced errors. For instance, as shown in Figure 20, the bot often selects an opening sequence that sets up a simple tactical trap. If the opponent plays carelessly, the bot can secure a quick win within just a few moves. However, an experienced player will immedi-

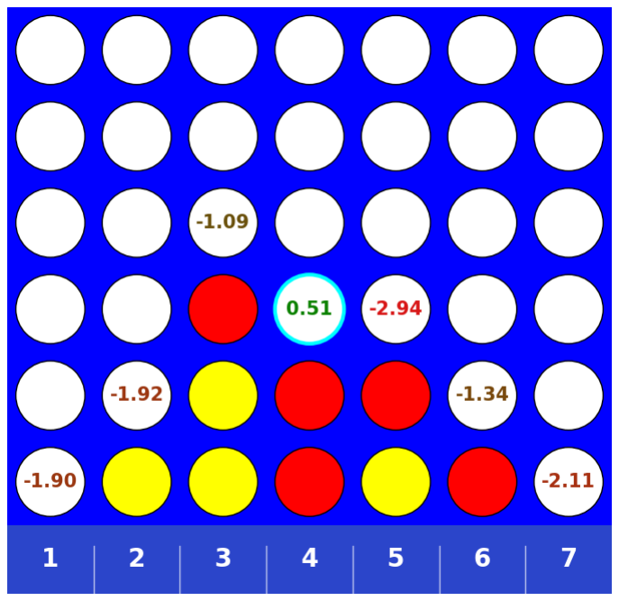
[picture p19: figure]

Figure 19 An MCS-driven bot (yellow) runs random playouts proceeding from playing at each column. A total of 1000 simulations were made, and the numbers for each move depict the total reward gained from that move normalized by the simulation count. A positive reward of 1 was given for each win, while a loss was penalized by -10. Column 4 is deemed the best move as it blocks a mate in 2 for red. Move 3 also blocks the immediate threat, which is why it is ranked second, but it is still a losing move, setting the game up for a loss further down the line. However, all other moves should be weighted equally badly, but here column 5 was calculated to be an especially terrible move. This is a result of sampling error skewing the results through noise.

ately recognize and neutralize the threat, rendering the sequence ineffective.
This stems from a shortcoming of MCS: since it runs random playouts, it treats all branches of the search tree equally. Since the algorithm does not differentiate between plausible and implausible lines of play, it assigns similar weight to all outcomes, even those highly unlikely to occur in real games. As a result, it may overvalue strategies that succeed frequently against naive or random play but fail against thoughtful opposition. (We have migitated this issue to a certain extent by penalizing losses more heavily than we reward wins.) This flaw becomes especially apparent in positions requiring subtle defense or multi-move planning. The bot might favor a line that appears strong statistically over one that would hold up against a skilled human. Consequently, while vanilla Monte Carlo can produce surprisingly effective moves in simple scenarios, its strategic depth is inherently limited.

### 7.2.2 Hard Mode: Monte Carlo Tree Search

To overcome the above drawbacks, Hard mode uses a more advanced form of simulation: Monte Carlo Tree Search (hereafter MCTS). Unlike vanilla MCS, which treats each simulation independently, MCTS learns from each simulation, building up a search tree that

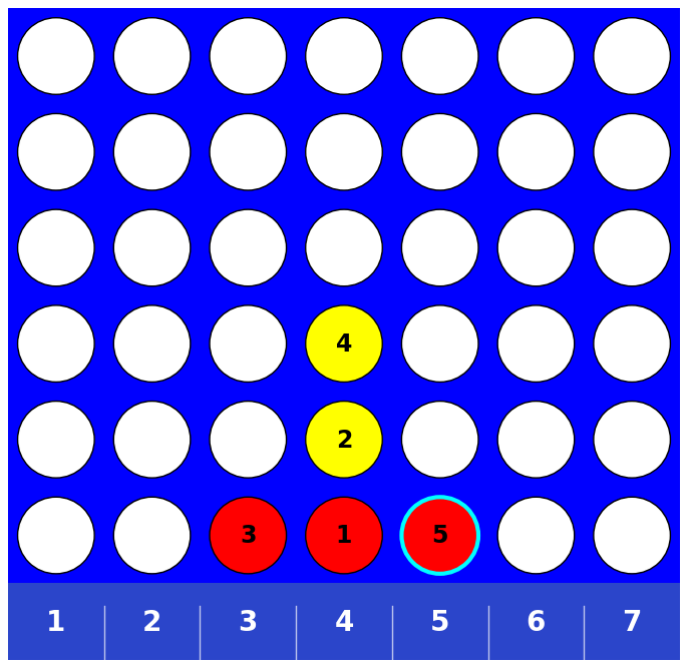
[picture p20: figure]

Figure 20 A common opening by the MCS-driven Medium level bot (red), with pieces numbered by move order. By playing at column 5 (highlighted), red creates a so-called double check, where regardless of where yellow plays, red wins in the next turn. However, an experienced opponent would not play at column 4 in their 4th move, and would instead block the threat by playing at 2 or 5, immediately nullifying the threat.

prioritizes promising moves over time. The algorithm selects nodes in the tree using the Upper Confidence Bound for Trees (UCT) formula, which prioritizes moves that have either shown strong results in past simulations (exploitation) or have been less explored and thus might reveal better outcomes if investigated further (exploration). The exploration-exploitable tradeoff is balanced with an exploration parameter that we set to √
2 as advised by the literature.
At this level, the algorithm works significantly more efficiently, enabling us to maintain the same total of 1,000 simulations while still observing sophisticated tactics and strategic depth. To validate the superiority of Monte Carlo Tree Search over vanilla Monte Carlo Simulation, we conducted experiments pitting an MCS-driven bot against an MCTS-driven bot, setting the total simulations parameter to 10,000 for each. The results were striking: MCTS beat MCS over 90% of the time. This clearly demonstrates the substantial advantage of MCTS in exploring the game tree more effectively and making smarter decisions.

### 7.2.3 Fine-tuning

To determine the optimal parameters for each level (e.g. the number of simulations for both MCS and MCTS, the exploration constant, and the final move selection strategy in MCTS), we conducted extensive experimentation. We tested various parameter combinations by having the Easy, Medium, and Hard bots compete against each other. For each pair of opponents, we simulated 1,000 games with one player starting first, and an additional 1,000 games with the other player starting, totaling 2,000 games per matchup. This thorough testing allowed us to identify the parameter settings that produced the most balanced win rates between different levels.
The results of these tests in the final configuration of the levels is depicted in Figure 21. The progression in skill level across the Easy, Medium, and Hard bots is clearly evident. We still see lower levels defeating higher ones now and then, which is a result of the stochastic nature of the algorithms.

Easy
starts

Medium
starts

0

200

400

600

800

1000

Games 88.8%

9.0%

95.9%

Easy vs Medium

Medium
starts

Hard
starts

0

200

400

600

800

1000

Games

70.3%

5.8%

23.9%

79.6%

4.7%

15.7%

Medium vs Hard

Easy
starts

Hard
starts

0

200

400

600

800

1000

Games 96.1% 98.7%

Easy vs Hard

Easy wins | Medium wins | Hard wins | Draws

Figure 21 Each of the 3 levels, Easy, Medium, and Hard, were played against each other. 2,000 games were simulated for each pair of opponents.

## 8 Evaluation and results

For the evaluation of the system’s performance especially the following measures should be considered:

1. Accuracy of the physical moves and precision when inserting the chip.
2. The rate at which the detection of the computer vision system is successful.
3. The win rate of the system against a human player

These metrics are chosen since they reflect well the different components on which we worked while developing the system. These metrics also ensure a good game experience for the user if all them are fulfilled with high scores.

For evaluating these metrics we performed several games with a human player against the robot. This allows us to evaluate all of the measures. For a quantitative evaluation we count the total number of moves performed and then count the number of incidents occurred. We map each of the incidents to the quality

Number
of
moves
played

Number
of
board
states

Cumulative
sum
0 | 1 | 1
1 | 7 | 8
2 | 49 | 57
3 | 238 | 295
4 | 1,120 | 1,415
5 | 4,263 | 5,678
6 | 16,422 | 22,100
7 | 54,859 | 76,959
8 | 184,275 | 261,234
9 | 558,186 | 819,420
10 | 1,662,623 | 2,482,043
11 | 4,568,683 | 7,050,726
12 | 12,236,101 | 19,286,827
13 | 30,929,111 | 50,215,938
14 | 75,437,595 | 125,653,533
15 | 176,541,259 | 302,194,792
16 | 394,591,391 | 696,786,183
17 | 858,218,743 | 1,555,004,926
18 | 1,763,883,894 | 3,318,888,820
19 | 3,568,259,802 | 6,887,148,622
20 | 6,746,155,945 | 13,633,304,567
21 | 12,673,345,045 | 26,306,649,612
22 | 22,010,823,988 | 48,317,473,600
23 | 38,263,228,189 | 86,580,701,789
24 | 60,830,813,459 | 147,411,515,248
25 | 97,266,114,959 | 244,677,630,207
26 | 140,728,569,039 | 385,406,199,246
27 | 205,289,508,055 | 590,695,707,301
28 | 268,057,611,944 | 858,753,319,245
29 | 352,626,845,666 | 1,211,380,164,911
30 | 410,378,505,447 | 1,621,758,670,358
31 | 479,206,477,733 | 2,100,965,148,091
32 | 488,906,447,183 | 2,589,871,595,274
33 | 496,636,890,702 | 3,086,508,485,976
34 | 433,471,730,336 | 3,519,980,216,312
35 | 370,947,887,723 | 3,890,928,104,035
36 | 266,313,901,222 | 4,157,242,005,257
37 | 183,615,682,381 | 4,340,857,687,638
38 | 104,004,465,349 | 4,444,862,152,987
39 | 55,156,010,773 | 4,500,018,163,760
40 | 22,695,896,495 | 4,522,714,060,255
41 | 7,811,825,938 | 4,530,525,886,193
42 | 1,459,332,899 | 4,531,985,219,092
Table 1 Number of possible board states with number of moves played

measures and so can calculate the percentage of moves causing problems. For the accuracy of the move, we count the move as successful if the coin was placed in the correct column and as false if it was not placed in the correct column or could not enter the column. For the computer vision we count a detection as not successful if the for a move relevant detection does not reflect the actual state of the game board. For the game rate, we count the wins by the system and by the player for the total number of games at the highest difficulty. The reason therefore is, that the other difficulties have the intention to let the player win.
The table 2 shows the results for incidents which occurred. We performed 10 games with a total of 154 moves.
Type of Measure | Successes | Errors | Success Percentage
Inserting the chip Game state detection | 152 154 | 2 0 | 98.7% 100.0%

Table 2 Evaluation results of system performance

The results underline the high reliability of the system with an accuracy of 100 % of the computer vision system. The issues with the coin drop were caused by irregularities on the coin surface resulting from production quality. This error can be resolved through appropriate post-processing and a high surface finish.

## 9 Discussion

The evaluation shows that the system performs with high precision and reliability and can so perform its task of playing connect 4 successfully. This is achieved by a cyber-physical system composed of different components including the mechanical design, electronics and system architecture as well as computer vision and the implemented game-algorithm. The implementation shows a successful approach how to implement the game connect-4 in a system that can play the game automatically against a human player. The defined requirements in the beginning of the project are so fulfilled.
The final result shows some trade offs which were made between different factors. The first version shows a clear tendency towards a fast development which is focused on building a working version and less optimized towards a final product. When deciding on the components and especially when choosing the lead screw mechanism we aimed for a high precision to ensure that the chips drop in the correct column. The lead screw mechanism thus is a bit slower in the movement compared to other possible movements but the tradeoff was made here in favor of the precision to ensure a high reliability of the system.
The system developed by us offers a system that fulfills the requirement of a system being capable to play connect 4. It finds its limitations in the size since the components are not optimized for a small sized version and much space is required. Furthermore since relying on the computer vision to detect the current game state, difficult light conditions such as strong light or also a lack of light in a room can cause problems for the system. We encounter this limitation by adding a calibration mechanism but in some edge cases it can still become a problem. These limitations describe the possible future work on the project which includes a development aiming towards a product which is smaller in size by using custom made components. In addition future mechanisms for the game state detection, such as detections in each column via light sensors to detect each inserted chip can be integrated and developed.

## 10 Conclusion

The development successfully includes the development of a reliable computer vision algorithm for the detection of the game state, the implementation of a game algorithm with a high win rate and the development of a electrical-mechanical system which is able to place chips with high precision in the correct column.
The project worked showed especially that calibration mechanisms (such as for the computer vision color calibration and the position of the stepper motor) increase the reliability of a system. In addition a key learning was made in the architecture of designing a distributed system of different components which communicate via serial connection to ensure an easy and reliable connection between different subsystems.

## List of Figures

1 | Direction of movement of base . . . . | 2
2 | Design of the base of the dropping
mechanism | | 3
3 | Holder for the chip | | 3
4 | Process of inserting a chip | | 3
5 | Construction of the magazine | | 4
6 | Rendering of the assembly of the dif-
ferent components | | 4
7 | Image of the complete v1 | | 4
8 | Rendering of the v2 | | 5
9 | Wiring diagram | | 6
10 | Image of the wiring | | 7
11 | Pipeline for processing one frame with
OpenCV | | 9
12 | Grid and prompt in the terminal . . . | 10
13 | Grid in terminal at end game | | 10
14 | Configuration screen | | 11
15 | Game screen | | 11
16 | Leaderboard | | 11
17 | Minimax algorithm: | Parsing the
search tree | | 12
18 | Minimax algorithm: Alpha-beta pruning 12
19 | How MCS chooses a move | | 13
20 | A favored opening of the MCS-driven
Medium level bot | | 14
21 | Each of the 3 levels, Easy, Medium,
and Hard, were played against each other. 2,000 games were simulated
for each pair of opponents | 14

## List of Tables

1 | Number of possible board states with
number of moves played | | 15
2 | Evaluation results of system perfor-
mance | | 15

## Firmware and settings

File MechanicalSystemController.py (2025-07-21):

import time
import board
import busio
import adafruit_pcf8574
import adafruit_vl53l0x
from adafruit_pca9685 import PCA9685
from tmc_driver.tmc_2209 import *
import RPi.GPIO as GPIO

# Constants for hardware configuration
STEPPER_POSITIONS_N = 9
STEPPER_COLUMN_SPACING = 20  # Spacing between columns in mm

# Stepper Motor and Lead Screw Specifications
# NEMA17 stepper: 1.8° per step = 200 steps per revolution
# Reference: https://www.omc-stepperonline.com/nema-17-stepper-motor
STEPPER_DEGREES_PER_STEP = 1.8  # Standard NEMA17 step angle
STEPPER_STEPS_PER_REV = 360 / STEPPER_DEGREES_PER_STEP  # 200 steps per revolution
LEADSCREW_PITCH_MM = 2.0  # Lead screw pitch in mm per revolution (common values: 1, 2, 4, 8mm)
                          # Adjust based on your actual lead screw specification
                          # Higher pitch = faster travel, lower precision

# Calculate steps per mm for positioning
# Steps per mm = (steps per revolution) / (mm per revolution)
STEPS_PER_MM = STEPPER_STEPS_PER_REV / LEADSCREW_PITCH_MM  # With microstepping, multiply by microstepping factor

# Position calculations (all in mm from home position)
STEPPER_LOADING_OFFSETS = [0, 8]  # Column positions for loaders (first and last columns)
STEPPER_LOADER1_POSITION_MM = -10.0  # Loader 1 position in mm (negative = before column 0)
STEPPER_LOADER2_POSITION_MM = (STEPPER_POSITIONS_N - 1) * STEPPER_COLUMN_SPACING + 10.0  # Loader 2 position (after last column)

STEPPER_DEFAULT_SPEED = 200  # Steps per second (will be converted to mm/s in calculations)

# TMC2209 Configuration Constants
# Reference: https://www.trinamic.com/fileadmin/assets/Products/ICs/TMC2209_Datasheet_V103.pdf
# MKS TMC2209 v2.0 specific guide: https://github.com/makerbase-mks/MKS-TMC2209
# Additional guide: https://github.com/Chr157i4n/TMC2209_Raspberry_Pi

# Setup GPIO pins for stepper control
# Adjust these pins based on your wiring
TMC2209_EN_PIN = 21   # Enable pin
TMC2209_DIR_PIN = 20  # Direction pin
TMC2209_STEP_PIN = 16 # Step pin
TMC2209_DIAG_PIN = 26 # Diagnostic pin
TMC2209_BAUDRATE = 115200  # UART communication speed - standard for MKS TMC2209 v2.0
TMC2209_DEFAULT_CURRENT = 600  # Motor current in mA (MKS v2.0 supports up to 2.8A peak)
                               # For NEMA17: typical 1.2-1.7A, start with 600-800mA
                               # MKS v2.0 current calculation: I_rms = (CS+1)/32 * Vref/(Rs*√2)
                               # Ref: MKS TMC2209 v2.0 manual section 3.2
TMC2209_HOMING_CURRENT = 300  # Reduced current for homing (50% of default)
                              # Lower current prevents damage when hitting mechanical limits
TMC2209_STALLGUARD_THRESHOLD = 63  # StallGuard sensitivity (0-255, higher = less sensitive)
                                   # MKS v2.0 recommended range: 50-100 for most steppers
                                   # Tune based on motor load and mechanical resistance
                                   # Ref: TMC2209 datasheet section 9.1
TMC2209_TCOOLTHRS = 20  # CoolStep lower threshold velocity (0-1048575)
                        # MKS v2.0: Above this velocity, CoolStep and StallGuard activate
                        # Lower values = more sensitive, but may cause false triggers
                        # Ref: TMC2209 datasheet section 6.4
TMC2209_SGTHRS = 63  # StallGuard threshold for sensorless homing (0-255)
                     # MKS v2.0: Lower values = more sensitive stall detection
                     # Start with 63, decrease if homing unreliable, increase if false triggers
                     # Must be tuned with actual load and motor characteristics
TMC2209_MICROSTEPPING = 16  # Microstepping resolution (1, 2, 4, 8, 16, 32, 64, 128, 256)
                            # MKS v2.0 supports up to 256 microsteps
                            # 16x provides good balance: smooth motion, adequate torque
                            # Higher values reduce torque but increase smoothness
                            # Ref: MKS TMC2209 v2.0 manual Table 2
TMC2209_HOMING_SPEED = 50  # Homing speed in steps/sec (adjust for microstepping)
                           # MKS v2.0: Too fast may miss stalls, too slow increases homing time
                           # With 16x microstepping: 50 steps/sec = ~3 RPM for 200-step motor
TMC2209_HOMING_OFFSET_STEPS = 50  # Steps to move away from limit after homing
                                  # MKS v2.0: Prevents continuous stall condition
                                  # Adjust based on mechanical backlash and precision needs
TMC2209_HOMING_MAX_STEPS = -10000  # Maximum steps during homing (negative for reverse)
                                   # MKS v2.0: Should exceed maximum travel distance
                                   # Safety limit to prevent infinite movement
TMC2209_HOMING_TIMEOUT = 5000  # Timeout in polling cycles (50 seconds at 0.01s intervals)
                               # MKS v2.0: Prevents infinite homing attempts
                               # Increase if mechanical system is slow
TMC2209_HOMING_SETTLE_TIME = 0.5  # Motor settle time after stall detection (seconds)
                                  # MKS v2.0: Allows mechanical vibrations to dampen
                                  # Critical for accurate position setting

# Servo Configuration Constants
# Standard servo control uses 50Hz PWM with 1-2ms pulse widths
# Reference: https://learn.adafruit.com/16-channel-pwm-servo-driver/using-the-adafruit-library
SERVO_DROP_CHANNEL = 0      # PCA9685 channel for token drop servo
SERVO_LOADER1_CHANNEL = 1   # PCA9685 channel for loader 1 servo
SERVO_LOADER2_CHANNEL = 2   # PCA9685 channel for loader 2 servo
SERVO_MIN_PULSE = 1000  # Minimum pulse width in microseconds (typically 1000-1500μs)
                        # Corresponds to 0° position for most servos
                        # Ref: https://www.servocity.com/how-does-a-servo-work
SERVO_MAX_PULSE = 2000  # Maximum pulse width in microseconds (typically 1500-2000μs)
                        # Corresponds to 180° position for most servos
SERVO_DROP_ANGLE = 90   # Angle for token drop action (degrees)
                        # Adjust based on mechanical design
SERVO_LOAD_ANGLE = 90   # Angle for loader activation (degrees)
                        # May need different values for each loader
SERVO_PWM_FREQUENCY = 50  # Standard servo frequency (50Hz = 20ms period)
                          # Most servos expect 50Hz, some can handle 100Hz
                          # Ref: PCA9685 datasheet and servo specifications
SERVO_ACTIVATION_TIME = 0.5  # Time to hold servo position (seconds)
                             # Allows mechanical action to complete

# VL53L0X ToF Sensor Constants
# Reference: https://www.st.com/en/imaging-and-photonics-solutions/vl53l0x.html
# Adafruit guide: https://learn.adafruit.com/adafruit-vl53l0x-micro-lidar-distance-sensor-breakout
VL53L0X_DEFAULT_ADDRESS = 0x29  # Factory default I2C address for VL53L0X
                                # All sensors start with this address
VL53L0X_1_XSHUT_PIN = "p0"     # Legacy pin naming (not used with new implementation)
VL53L0X_2_XSHUT_PIN = "p1"     # Legacy pin naming (not used with new implementation)
TOF1_ADDRESS = 0x30  # New I2C address for first sensor after address change
                     # Valid range: 0x08-0x77 (avoid reserved addresses)
TOF2_ADDRESS = 0x31  # New I2C address for second sensor after address change
                     # Must be different from TOF1_ADDRESS
TOF_FULL_THRESHOLD_MM = 30   # Distance indicating loader is full (millimeters)
                             # VL53L0X range: 30-2000mm (optimal: 50-1200mm)
                             # Adjust based on token size and loader geometry
TOF_EMPTY_THRESHOLD_MM = 100  # Distance indicating loader is empty (millimeters)
                              # Should be > TOF_FULL_THRESHOLD_MM + safety margin
TOF_INIT_DELAY = 0.01  # Delay during sensor initialization (seconds)
                       # Required for proper I2C communication timing
                       # Ref: VL53L0X datasheet timing requirements

# I2C Device Addresses
# Standard 7-bit I2C addresses - check with i2cdetect command
# Reference: https://learn.adafruit.com/i2c-addresses/the-list
PCF8574_ADDRESS = 0x20  # PCF8574 I2C expander address
                        # Default range: 0x20-0x27 (A0,A1,A2 pins set address)
                        # Datasheet: https://www.ti.com/lit/ds/symlink/pcf8574.pdf
PCA9685_ADDRESS = 0x40  # PCA9685 PWM driver address
                        # Default range: 0x40-0x7F (A0-A5 pins set address)
                        # Datasheet: https://www.nxp.com/docs/en/data-sheet/PCA9685.pdf

# PCF8574 Pin Mapping
# PCF8574 has 8 I/O pins (P0-P7), all bidirectional with weak pull-ups
# Reference: PCF8574 datasheet section 7.1
PCF8574_TOF1_XSHUT_PIN = 0  # Pin P0 for ToF sensor 1 XSHUT control
                            # XSHUT pin controls sensor power/reset state
PCF8574_TOF2_XSHUT_PIN = 1  # Pin P1 for ToF sensor 2 XSHUT control
                            # HIGH = sensor active, LOW = sensor in reset

# Timing Constants
# Fine-tuned for reliable operation and responsiveness
MOVEMENT_POLL_INTERVAL = 0.01  # Polling interval for movement completion (seconds)
                               # Balance between responsiveness and CPU usage
                               # Too fast = high CPU load, too slow = delayed response
EMERGENCY_STOP_DELAY = 0.1     # Delay after emergency stop (seconds)
                               # Allows motor driver to process stop command

class MechanicalSystemController:
    """
    Controls the mechanical subsystem: stepper, servos, and ToF sensors.
    """
    def __init__(self, i2c_bus=None, stepper_uart_port="/dev/serial0", stepper_address=0):
        try:
            self.i2c = i2c_bus or busio.I2C(board.SCL, board.SDA)
            
            # Initialize GPIO
            GPIO.setmode(GPIO.BCM)
            GPIO.setup(TMC2209_EN_PIN, GPIO.OUT)
            GPIO.setup(TMC2209_DIR_PIN, GPIO.OUT)
            GPIO.setup(TMC2209_STEP_PIN, GPIO.OUT)
            
            # Create TMC control objects
            tmc_enable_control = TmcEnableControl(enable_pin=TMC2209_EN_PIN)
            tmc_motion_control = TmcMotionControl(dir_pin=TMC2209_DIR_PIN, step_pin=TMC2209_STEP_PIN)
            tmc_com = TmcCom(uart_port=stepper_uart_port, baudrate=TMC2209_BAUDRATE)
            
            # Initialize TMC2209 stepper driver with proper constructor
            self.stepper = Tmc2209(
                tmc_ec=tmc_enable_control,
                tmc_mc=tmc_motion_control,
                tmc_com=tmc_com,
                driver_address=stepper_address
            )
            
            # Configure TMC2209 settings
            self.stepper.set_direction_reg(False)
            self.stepper.set_current(TMC2209_DEFAULT_CURRENT)
            self.stepper.set_interpolation(True)
            self.stepper.set_spreadcycle(False)
            self.stepper.set_microstepping_resolution(TMC2209_MICROSTEPPING)
            
            # Configure stallGuard for sensorless homing
            self.stepper.set_stallguard_threshold(TMC2209_STALLGUARD_THRESHOLD)
            self.stepper.set_tcoolthrs(TMC2209_TCOOLTHRS)
            self.stepper.set_sgthrs(TMC2209_SGTHRS)
            
            self.stepper.set_motor_enabled(True)
            
            # Initialize PCF8574 with Adafruit library
            self.pcf = adafruit_pcf8574.PCF8574(self.i2c, address=PCF8574_ADDRESS)
            
            # Hold both sensors in reset to assign addresses
            self.pcf[PCF8574_TOF1_XSHUT_PIN].value = False
            self.pcf[PCF8574_TOF2_XSHUT_PIN].value = False
            time.sleep(TOF_INIT_DELAY)

            # Power up sensor 1 only, assign new address
            self.pcf[PCF8574_TOF1_XSHUT_PIN].value = True
            time.sleep(TOF_INIT_DELAY)
            vl53_1 = adafruit_vl53l0x.VL53L0X(self.i2c)
            vl53_1.set_address(TOF1_ADDRESS)
            time.sleep(TOF_INIT_DELAY)

            # Power up sensor 2 only, assign new address
            self.pcf[PCF8574_TOF2_XSHUT_PIN].value = True
            time.sleep(TOF_INIT_DELAY)
            vl53_2 = adafruit_vl53l0x.VL53L0X(self.i2c)
            vl53_2.set_address(TOF2_ADDRESS)
            time.sleep(TOF_INIT_DELAY)

            # Re-initialize both sensors at their new addresses
            self.tof1 = adafruit_vl53l0x.VL53L0X(self.i2c, address=TOF1_ADDRESS)
            self.tof2 = adafruit_vl53l0x.VL53L0X(self.i2c, address=TOF2_ADDRESS)

            # Initialize PCA9685 for servo control
            self.pca = PCA9685(self.i2c, address=PCA9685_ADDRESS)
            self.pca.frequency = SERVO_PWM_FREQUENCY

            # Calculate actual steps per mm including microstepping
            self.steps_per_mm = STEPS_PER_MM * TMC2209_MICROSTEPPING
            print(f"Calculated steps per mm: {self.steps_per_mm}")
            
            # Track stepper position
            self.current_position = 0
            self.stepper_steps_from_home = 0
            self.is_homed = False
            
        except Exception as e:
            raise RuntimeError(f"Initialization failed: {e}")

    def _mm_to_steps(self, distance_mm):
        """
        Convert millimeter distance to motor steps.
        
        Args:
            distance_mm (float): Distance in millimeters
            
        Returns:
            int: Number of steps required
        """
        return int(distance_mm * self.steps_per_mm)

    def _column_to_mm(self, column):
        """
        Convert column number to millimeter position.
        
        Args:
            column (int): Column number (0-8)
            
        Returns:
            float: Position in millimeters from home
        """
        if column in STEPPER_LOADING_OFFSETS:
            if column == 0:
                return STEPPER_LOADER1_POSITION_MM
            elif column == 8:
                return STEPPER_LOADER2_POSITION_MM
        else:
            # Regular column position
            return column * STEPPER_COLUMN_SPACING
        
        raise ValueError(f"Invalid column number: {column}")

    # --- Stepper Motor Control ---

    def home_stepper(self):
        """
        Home the stepper motor using stallGuard sensorless homing.
        Drives to the mechanical limit until stall is detected via DIAG pin.
        """
        try:
            print("Starting sensorless homing...")
            
            # Set lower current for homing to reduce impact
            self.stepper.set_current(TMC2209_HOMING_CURRENT)
            
            # Enable stallGuard for homing
            self.stepper.set_stallguard_threshold(TMC2209_STALLGUARD_THRESHOLD)
            
            # Set homing speed
            self.stepper.set_max_speed(TMC2209_HOMING_SPEED)
            
            # Move towards home position
            self.stepper.set_movement_abs_rel(MovementAbsRel.relative)
            
            # Start moving towards limit
            self.stepper.run_to_position_steps(TMC2209_HOMING_MAX_STEPS)
            
            # Monitor stallGuard result until stall is detected
            stall_detected = False
            timeout_counter = 0
            
            while not stall_detected and timeout_counter < TMC2209_HOMING_TIMEOUT:
                sg_result = self.stepper.get_stallguard_result()
                if sg_result == 0:  # StallGuard triggered (stall detected)
                    stall_detected = True
                    self.stepper.stop()
                    print("Stall detected - home position found")
                    break
                    
                time.sleep(MOVEMENT_POLL_INTERVAL)
                timeout_counter += 1
            
            if not stall_detected:
                raise RuntimeError("Homing timeout - no stall detected")
            
            # Stop and wait for motor to settle
            time.sleep(TMC2209_HOMING_SETTLE_TIME)
            
            # Reset position counter to zero (this is now home)
            self.stepper.set_actual_position(0)
            
            # Move slightly away from the limit to avoid continuous stall
            self.stepper.run_to_position_steps(TMC2209_HOMING_OFFSET_STEPS)
            while not self.stepper.is_movement_finished():
                time.sleep(MOVEMENT_POLL_INTERVAL)
            
            # Reset position to zero after offset
            self.stepper.set_actual_position(0)
            
            # Restore original current and speed
            self.stepper.set_current(TMC2209_DEFAULT_CURRENT)
            self.stepper.set_max_speed(STEPPER_DEFAULT_SPEED)
            
            # Update internal tracking
            self.current_position = 0
            self.stepper_steps_from_home = 0
            self.is_homed = True
            
            print("Sensorless homing completed successfully")
            
        except Exception as e:
            print(f"Stepper homing error: {e}")
            self.is_homed = False
            # Restore original settings even on error
            try:
                self.stepper.set_current(TMC2209_DEFAULT_CURRENT)
                self.stepper.set_max_speed(STEPPER_DEFAULT_SPEED)
            except:
                pass

    def move_stepper_to(self, position):
        """
        Move the stepper to one of 9 positions (0-8).
        Positions 0 and 8 are loader offsets; 1-7 are board columns.
        Calculates actual mm position and converts to steps.
        """
        if not (0 <= position < STEPPER_POSITIONS_N):
            raise ValueError("Invalid stepper position")
        
        if not self.is_homed:
            print("Warning: Stepper not homed. Attempting to home first.")
            self.home_stepper()
            if not self.is_homed:
                raise RuntimeError("Cannot move stepper - homing failed")
        
        try:
            # Make sure the drop servo is in the upright position
            self.reset_drop_servo()
            
            # Convert column number to mm position
            target_position_mm = self._column_to_mm(position)
            
            # Convert mm to steps
            target_steps = self._mm_to_steps(target_position_mm)
            
            print(f"Moving to column {position}: {target_position_mm}mm = {target_steps} steps")

            # Set movement speed
            self.stepper.set_movement_abs_rel(MovementAbsRel.absolute)
            self.stepper.set_max_speed(STEPPER_DEFAULT_SPEED)
            
            # Move to absolute position
            self.stepper.run_to_position_steps(target_steps)
            
            # Wait for movement to complete
            while not self.stepper.is_movement_finished():
                time.sleep(MOVEMENT_POLL_INTERVAL)

            self.current_position = position
            self.stepper_steps_from_home = target_steps
            print(f"Stepper moved to position {position} ({target_position_mm}mm)")
            
        except Exception as e:
            print(f"Stepper move error: {e}")
            raise

    def move_stepper_to_loader(self):
        """
        Move the stepper to the closest loader if not empty

        Returns:
            int: Index of loader at the current position
        """
        if self.current_position in [0, 8]:
            return self.get_loader_index()

        if self.current_position <= 4 and self.is_loader_full(1):
            self.move_stepper_to(0)
            return 1
        else:
            self.move_stepper_to(8)
            return 2

    def get_current_position_mm(self):
        """
        Get the current position in millimeters.
        
        Returns:
            float: Current position in mm from home
        """
        return self.stepper_steps_from_home / self.steps_per_mm

    def get_stepper_position(self):
        """
        Get the current logical position of the stepper motor.
        """
        return self.current_position

    def stop_stepper(self):
        """
        Emergency stop for the stepper motor.
        """
        try:
            self.stepper.stop()
            time.sleep(EMERGENCY_STOP_DELAY)
        except Exception as e:
            print(f"Stepper stop error: {e}")

    # --- Servo Control ---

    def drop_token_and_rest(self):
        """
        Rotate the drop servo to drop a token, then reset.
        """
        try:
            self._set_servo_angle(SERVO_DROP_CHANNEL, SERVO_DROP_ANGLE)
            time.sleep(SERVO_ACTIVATION_TIME)
            self._set_servo_angle(SERVO_DROP_CHANNEL, 0)
        except Exception as e:
            print(f"Drop servo error: {e}")

    def drop_token(self):
        """
        Roatate the drop servo to drop a token, without resetting.
        """
        try:
            self._set_servo_angle(SERVO_DROP_CHANNEL, SERVO_DROP_ANGLE)
        except Exception as e:
            print(f"Drop servo error: {e}")

    def reset_drop_servo(self):
        """
        Roatate the drop servo to reset position
        """
        try:
            self._set_servo_angle(SERVO_DROP_CHANNEL, 0)
        except Exception as e:
            print(f"Drop servo error: {e}")

    def activate_loader(self, loader_num):
        """
        Activate one of the two loader servos (1 or 2).
        """
        if loader_num not in [1, 2]:
            raise ValueError("Loader number must be 1 or 2")
        channel = SERVO_LOADER1_CHANNEL if loader_num == 1 else SERVO_LOADER2_CHANNEL
        try:
            self._set_servo_angle(channel, SERVO_LOAD_ANGLE)
            time.sleep(SERVO_ACTIVATION_TIME)
            self._set_servo_angle(channel, 0)
        except Exception as e:
            print(f"Loader servo error: {e}")
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

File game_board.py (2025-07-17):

import os
import numpy as np
import modules.board_param as param

class Board:
	def __init__(self, *args):
		if len(args) == 1 and isinstance(args[0], np.ndarray) and args[0].ndim == 2:
			self.board_array = args[0]
		else:
			self.board_array = np.zeros((param.ROW_COUNT, param.COLUMN_COUNT), dtype=np.int8)

		self.winning_cells = []
		self.last_play = (-1, -1)
		
	def pretty_print_board(self):
		flipped_last_play = (5 - self.last_play[0], self.last_play[1])
		flipped_board = np.flipud(self.board_array)

		os.system('cls' if os.name == 'nt' else 'clear') # clear the terminal
		print("\033[0;37;44m 0 \033[0;37;44m 1 \033[0;37;44m 2 \033[0;37;44m 3 \033[0;37;44m 4 \033[0;37;44m 5 \033[0;37;44m 6 \033[0m")
		for i, row in enumerate(flipped_board):
			row_str = "" 

			for j, cell in enumerate(row):
				if (i, j) in self.winning_cells:
					text = "42m " + ("1" if cell == param.PLAYER_PIECE else "2") # green
				elif cell == param.BOT_PIECE:
					text = "43m 2" # yellow
				elif cell == param.PLAYER_PIECE:
					text = "41m 1" # red
				else:
					text = "46m  " # cyan

				row_str += "\033[0;37;" + text + ("*" if flipped_last_play == (i, j) else " ")

			# print(repr(row_str))
			print(row_str+"\033[0m")
		print("\033[0;37;44m 0 \033[0;37;44m 1 \033[0;37;44m 2 \033[0;37;44m 3 \033[0;37;44m 4 \033[0;37;44m 5 \033[0;37;44m 6 \033[0m")

	def get_valid_locations(self):
		"""
		Returns list of valid columns that can be played
		"""
		valid_locations = []
		for col in range(param.COLUMN_COUNT):
			if self.is_valid_location(col):
				valid_locations.append(col)

		return valid_locations
	
	def is_valid_location(self, col):
		return self.board_array[param.ROW_COUNT - 1][col] == 0

	def is_valid_board(self):
		# For each column, check that there are no empty cells below a filled cell
		for col in range(param.COLUMN_COUNT):
			found_empty = False
			for row in range(param.ROW_COUNT):
				if self.board_array[row][col] == 0:
					found_empty = True
				elif found_empty:
					# Found a token above an empty cell, invalid board
					return False
		return True
	
	# TODO add more error / cheating & interim state handling
	def get_valid_state(self, new_grid):
		new_board = Board(new_grid)

		# First, check if the new board is valid
		if not new_board.is_valid_board():
			return None

		# The new board must have exactly one more token than the old board
		old_count = np.count_nonzero(self.board_array)
		new_count = np.count_nonzero(new_board.board_array)
		#print(f"old count:{old_count}, new count:{new_count}")
		if new_count != old_count + 1:
			return None
		# Find the difference between the boards
		diff = new_board.board_array - self.board_array
		changed_positions = np.argwhere(diff != 0)

		# There must be exactly one changed position
		if changed_positions.shape[0] != 1:
			return None

		row, col = changed_positions[0]
		# The change must be on top of the stack (all rows below must be non-empty in new_board)
		if row > 0 and new_board.board_array[row-1][col] == 0:
			return None

		return int(col)

	def drop_piece(self, col, piece):
		for row in range(param.ROW_COUNT):
			if self.board_array[row][col] == 0:
				self.board_array[row][col] = piece
				self.last_play = (row, col)
				break

	def winning_move(self, piece):
		flipped_board = np.flipud(self.board_array)

		# Check valid horizontal locations for win
		for c in range(param.COLUMN_COUNT - param.WINDOW_LENGTH + 1):
			for r in range(param.ROW_COUNT):
				if all(flipped_board[r][c + i] == piece for i in range(param.WINDOW_LENGTH)):
					self.winning_cells = [(r, c + i) for i in range(param.WINDOW_LENGTH)]
					return True

		# Check valid vertical locations for win
		for c in range(param.COLUMN_COUNT):
			for r in range(param.ROW_COUNT - param.WINDOW_LENGTH + 1):
				if all(flipped_board[r + i][c] == piece for i in range(param.WINDOW_LENGTH)):
					self.winning_cells = [(r + i, c) for i in range(param.WINDOW_LENGTH)]
					return True

		# Check valid positive diagonal locations for win
		for c in range(param.COLUMN_COUNT - param.WINDOW_LENGTH + 1):
			for r in range(param.ROW_COUNT - param.WINDOW_LENGTH + 1):
				if all(flipped_board[r + i][c + i] == piece for i in range(param.WINDOW_LENGTH)):
					self.winning_cells = [(r + i, c + i) for i in range(param.WINDOW_LENGTH)]
					return True

		# check valid negative diagonal locations for win
		for c in range(param.COLUMN_COUNT - param.WINDOW_LENGTH + 1):
			for r in range(param.WINDOW_LENGTH - 1, param.ROW_COUNT):
				if all(flipped_board[r - i][c + i] == piece for i in range(param.WINDOW_LENGTH)):
					self.winning_cells = [(r - i, c + i) for i in range(param.WINDOW_LENGTH)]
					return True

		self.winning_cells = []
		return False

	def score_position(self, piece):
		score = 0

		# Score centre column
		centre_array = [int(i) for i in list(self.board_array[:, param.COLUMN_COUNT // 2])]
		centre_count = centre_array.count(piece)
		score += centre_count * (param.WINDOW_LENGTH - 1)
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

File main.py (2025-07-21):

# code from https://roboticsproject.readthedocs.io/en/latest/ConnectFourAlgorithm.html
import argparse
import json
import os
import time
import random
import logging
import numpy as np

import multiprocessing as mp
from multiprocessing import Manager

from camera_grid import Grid
from camera import Camera
from game_board import Board
from plays import easy_play, medium_play, hard_play, optimal_play

import modules.board_param as param

# Configure logging
logging.basicConfig(level=logging.INFO, format='%(asctime)s - %(levelname)s - %(message)s')
logger = logging.getLogger(__name__)

motor_controller = None
camera_process = None

# Global variables for feedback system
move_messages = {}

def load_move_messages():
    """Load move evaluation messages from JSON file"""
    global move_messages
    try:
        with open('move_messages.json', 'r') as f:
            move_messages = json.load(f)
        logger.info("Move messages loaded successfully")
    except (FileNotFoundError, json.JSONDecodeError) as e:
        logger.warning(f"Failed to load move messages: {e}")
        # Fallback to default messages if file is missing
        move_messages = {
            "bad": ["That move could use some work.", "Not your best move.", "Try to think ahead next time."],
            "mid": ["An okay move.", "Decent choice.", "A reasonable play."],
            "good": ["Nice move!", "Excellent choice!", "Great thinking!", "Well played!"]
        }

def evaluate_move_quality(board, col, scores):
    """Evaluate the quality of a player's move based on scores"""
    if not scores or col >= len(scores):
        return "mid"  # Default to mid if no scores available

    move_score = scores[col]
    valid_moves = board.get_valid_locations()
    valid_scores = [scores[i] for i in valid_moves if i < len(scores)]

    if not valid_scores:
        return "mid"

    best_score = max(valid_scores)
    worst_score = min(valid_scores)

    # If all moves have the same score, it's mid
    if best_score == worst_score:
        return "mid"

    score_range = best_score - worst_score
    threshold_good = max(best_score - (score_range * 0.2), -10)  # Top 20%
    threshold_bad = worst_score + (score_range * 0.3)  # Bottom 30%

    if move_score >= threshold_good:
        return "good"
    elif move_score <= threshold_bad:
        return "bad"
    else:
        return "mid"

def get_move_message(quality):
    """Get a random message for the move quality"""
    return random.choice(move_messages.get(quality, ["Move made."]))

def evaluate_player_move(board, col, lookup_table, shared_dict):
    """Evaluate player's move and store feedback in shared_dict"""
    try:
        from plays.plays import calculate_board_scores

        # Get scores for current board position
        scores = calculate_board_scores(board.board_array, lookup_table)

        if scores:
            quality = evaluate_move_quality(board, col, scores)
            move_message = get_move_message(quality)
            logger.info(f"Move quality: {quality}, Message: {move_message}")

            # Store feedback in shared dict
            shared_dict["move_message"] = move_message

            # Store scores for training mode display
            training_mode = shared_dict.get("training_mode", False)
            if training_mode:
                shared_dict["scores"] = scores
        else:
            logger.warning("Could not calculate scores for move evaluation")

    except Exception as e:
        logger.error(f"Error in move evaluation: {e}")

def update_training_scores(board, lookup_table, shared_dict):
    """Update scores for training mode display"""
    training_mode = shared_dict.get("training_mode", False)
    if training_mode:
        try:
            from plays.plays import calculate_board_scores
            scores = calculate_board_scores(board.board_array, lookup_table)
            if scores:
                shared_dict["scores"] = scores
                logger.info("Training mode scores updated")
        except Exception as e:
            logger.error(f"Error updating training scores: {e}")
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

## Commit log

2025-05-07 cv is crashing if boundary
    [camera.py, cv.py]
2025-05-21 add detection with fix grid
    [calibrate_mask_range.py, grid_fix.py, srceen_ui.ino]
2025-05-24 try color correction + servo sketch
    [calibrate_mask_range.py, grid_fix.py, servo.ino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]
2025-05-26 added stepper dir
2025-05-26 added arduino sketch
2025-05-27 convert ino code for raspberry pi in python
2025-05-27 move stepper sketch to proper folder
2025-06-10 Save lookup_table - optimal openings for first 4 moves. After 4 moves, thinking time does not seem to take longer than 2s at max, and near instant on average.
    Slight bug fixing
    Add play_from_terminal.py for debugging purposes
    [main.py]
2025-06-17 added stepper stuff
2025-06-17 added stepper homing sketch
2025-06-17 fixed homing
2025-06-19 Renaming connect4 algo to avoid confusion
    Before the connect4 algorithm was installed under the name 'connect4'
    which could create conflict with another python library.
    To avoid this, the algo is now installed under 'connect4_alg'
    and at the import, it will look for the local module 'connect4_alg' first (where the binary file is now imported) instead of searching at the top level.
    [camera.py, main.py]
2025-06-19 working camera
2025-06-19 trying to fix timing
    [main.py]
2025-06-24 [fix] removed the sleep, issue was a lose cable.
    [main.py]
2025-06-24 Optimal play takes in board object as parameter instead of board_array
2025-06-24 play_turn is now a Board method instead of a function in main.py
2025-06-24 major ESP32 controll refactor
2025-06-24 Bugfix during hard play
    [game_board.py]
2025-07-06 fixing #1. Add yaml config file for camera parameters
    [calibrate_mask_range.py, camera.py, main.py]
2025-07-06 fixing #3. Circle outside of the grid area are no longer detected
    [camera.py, camera_grid.py]
2025-07-08 add gui option for raspberry pi
2025-07-09 handeling camera exception
2025-07-09 error with camera init
    [camera.py, main.py]
2025-07-09 fix end of game
    [camera.py, main.py]
2025-07-10 added kicad schematics
    [12-5_step-down.kicad_sch, Adafruit PCA9685 rev C.kicad_sch, Adafruit TMC2209 Stepper Motor Driver.kicad_sch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]
2025-07-10 fixed constructor to comply with library
    [MechanicalSystemController.py]
2025-07-11 fix serial communication in game loop
    [main.py, stepper.py]
2025-07-11 fixed bug with serial comunication (ESP32 side)
    [stepper_with_homing_and_servos.ino]
2025-07-16 fix typo and small changes in compute grid logic
    [camera.py, camera_grid.py]
2025-07-19 add camera process start from api
2025-07-19 fix for automatic ui launch
    [api.py]
2025-07-20 add servo/stepper methods for game logic
2025-07-21 update launch file and api camera endpoint
2025-07-21 block game and motors if coin not dropped properly
